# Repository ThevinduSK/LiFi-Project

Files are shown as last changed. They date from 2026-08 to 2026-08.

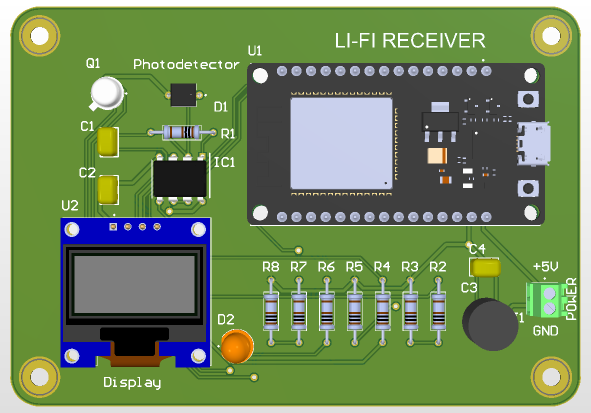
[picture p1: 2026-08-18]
PCB/Receiver/PCB 3D Print/PCB1.png

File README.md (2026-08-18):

# ESP32 Li-Fi Communication and Security Demonstrator

This repository contains the firmware and design files for a three-node
visible-light communication experiment:

1. A **transmitter** sends short messages by switching a high-power white LED.
2. A **legitimate receiver** detects the light with a BPW34 photodiode and
   displays valid messages on an OLED.
3. An **eavesdropper receiver** will later be used to measure how much of the
   optical signal can be recovered from an unintended position.

The current firmware is a compiled proof-of-concept for the first two nodes.
It uses on-off keying (OOK), Manchester line coding, framed messages, CRC-8
error detection, and a 38 kHz infrared acknowledgment path. It has not yet
been validated on the assembled PCBs.

For the complete design, security scope, implementation status, and test plan,
see [Project Technical Design and Status](docs/PROJECT_TECHNICAL_DESIGN_AND_STATUS.md).

## Current status

| Area | Status |
|---|---|
| PlatformIO ESP32 project | Implemented |
| Transmitter and receiver pin definitions | Implemented from supplied schematics |
| OOK and Manchester transmitter | Implemented and compiles |
| ADC Manchester receiver | Implemented and compiles |
| Message framing and CRC-8 | Implemented and compiles |
| OLED message display | Implemented and compiles |
| 38 kHz IR acknowledgment | Implemented and compiles |
| Separate hardware diagnostic firmware | Planned next |
| On-demand `A` link-quality handshake | Planned next |
| Simple `B` normal-message mode | Planned next |
| SNR and known-sequence success measurement | Planned next |
| Physical PCB testing and tuning | Not started |
| Eavesdropper experiment | Deferred until the legitimate link is stable |
| Encryption/authentication | Not implemented; optional later scope |

“Compiles” means PlatformIO successfully built the firmware. It does not mean
that the code has been uploaded to a board or that the optical thresholds and
timing have been proven on the physical link.

## Intended user workflow

The next firmware revision will use a deliberately small interface:

- Press `A` to run a link test. The transmitter sends a known optical sequence.
  The receiver estimates optical SNR and bit success rate, displays the result,
  and returns an IR result to the transmitter.
- Press `B` to enter normal message mode. Enter a short message, use `*` to
  erase, and press `#` to transmit.
- Normal messages will retain a short start marker and CRC, but will not repeat
  the full training/calibration sequence or wait for an IR ACK after every
  message.
- Run `A` again when the distance, alignment, ambient lighting, or LED level
  changes significantly.

The code currently in `src/transmitter` and `src/receiver` is the earlier full
prototype: it performs optical calibration and waits for an IR ACK on every
message. That behavior is documented, but will be simplified in the next
implementation stage.

## Hardware pin map

The pin assignments below match the supplied transmitter and receiver
schematics.

### Transmitter ESP32

| Function | GPIO |
|---|---:|
| White LED MOSFET gate | 18 |
| Warning/status LED | 23 |
| IR acknowledgment receiver | 19 |
| Keypad rows R1-R4 | 13, 14, 27, 26 |
| Keypad columns C1-C4 | 25, 33, 32, 16 |

### Legitimate receiver ESP32

| Function | GPIO |
|---|---:|
| BPW34/LM358 analog output | 34 |
| IR acknowledgment transmitter | 18 |
| OLED SDA | 21 |
| OLED SCL | 22 |

The transmitter firmware starts the high-power LED output in the OFF state.
LED current is determined by the external LED, supply, resistor, MOSFET, and
thermal design—not by the ESP32 firmware.

## Repository layout

```text
.
├── docs/                         Detailed design and progress document
├── include/
│   ├── lifi_protocol.hpp         Protocol constants and CRC-8
│   └── pin_config.hpp            Schematic-derived ESP32 pin assignments
├── PCB/
│   ├── Transmitter/              Transmitter schematic and fabrication files
│   └── Receiver/                 Receiver schematic and fabrication files
├── src/
│   ├── transmitter/main.cpp      Current transmitter proof-of-concept
│   ├── receiver/main.cpp         Current receiver proof-of-concept
│   └── eavesdropper/main.cpp     Placeholder for the later experiment
└── platformio.ini                PlatformIO environments and dependencies
```

## Building with PlatformIO

Open this repository as the project folder in VS Code. PlatformIO should show
the `transmitter`, `receiver`, and `eavesdropper` environments.

Build the two active nodes:

```bash
pio run -e transmitter
pio run -e receiver
```

Upload one environment after connecting the correct ESP32:

```bash
pio run -e transmitter -t upload
pio run -e receiver -t upload
```

Open the serial monitor at 115200 baud:

```bash
pio device monitor --baud 115200
```

Do not connect both ESP32 boards at once unless the upload port is selected
explicitly. Before powering the high-power LED stage, verify its supply,
polarity, current-limiting component, and thermal requirements.

## Current proof-of-concept controls

These controls describe the code presently in the repository, before the
planned `A`/`B` mode separation:

- `0-9` and `A-D`: append a character.
- `*`: erase the last character.
- `#`: transmit the message.
- Serial Monitor input follows the same rules; newline also transmits.
- Maximum message length: 16 characters.

## Important security statement

This is a **Li-Fi security demonstrator**, not yet a secure messaging product.
Directional visible light may reduce casual signal exposure, but it does not
guarantee confidentiality. CRC detects accidental corruption; it does not
authenticate a sender or prevent deliberate modification. The IR ACK proves
only that an IR response was detected, not that no passive eavesdropper was
present.

The security contribution will be the measured comparison between the
legitimate receiver and an eavesdropper under controlled placement, angle,
distance, obstruction, and ambient-light conditions. Cryptographic protection
can be added later if it becomes part of the project scope.

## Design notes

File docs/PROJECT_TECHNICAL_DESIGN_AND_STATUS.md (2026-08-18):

# Li-Fi Communication and Security Demonstrator

## Technical Design and Project Status

**Document date:** 18 August 2026  
**Implementation platform:** ESP32 DevKit V1, Arduino framework, PlatformIO  
**Project stage:** Legitimate transmitter/receiver proof-of-concept; hardware
bring-up and simplified operating modes are the next milestone

## 1. Executive summary

The project demonstrates short-range digital communication through visible
light and studies the practical security boundary of that link. A transmitter
modulates a high-power white LED, a legitimate receiver recovers the data with
a photodiode circuit, and a later eavesdropper node attempts to recover the same
data from unintended locations.

The first software proof-of-concept is present and builds successfully. It can:

- accept a short message from a 4x4 keypad or Serial Monitor;
- encode it into a structured frame;
- transmit the frame through the white LED using on-off keying and Manchester
  line coding;
- sample the photodiode amplifier through the receiver ESP32 ADC;
- validate a received frame with CRC-8;
- display a valid payload on the OLED; and
- return a 38 kHz IR acknowledgment to the transmitter.

This code has not yet been proven on the assembled PCBs. It also performs a
calibration preamble and acknowledgment for every message, which is more
complex than needed for the first demonstration. The agreed next revision will
separate an on-demand link test from normal message transmission:

- `A`: run a known-sequence link test, measure quality, show the result, and
  return an IR response;
- `B`: enter normal message mode and send short messages using the most recent
  link calibration.

The eavesdropper work will begin only after this basic legitimate link is
repeatable.

## 2. Project purpose and scope

### 2.1 Primary objectives

1. Establish a repeatable one-way visible-light data link between two ESP32
   systems.
2. Provide a simple keypad-operated demonstration that is easy to understand.
3. Measure legitimate link quality using a known test sequence.
4. Build a third receiving node and compare its recovery performance against
   the legitimate receiver.
5. Record how geometry and environment affect both communication reliability
   and exposure to eavesdropping.

### 2.2 Initial deliverable

The initial deliverable is a laboratory demonstrator, not a high-speed Li-Fi
network. It prioritizes observable operation, simple debugging, and repeatable
measurements over data rate.

### 2.3 Items outside the current implementation

- encryption and cryptographic authentication;
- high-speed data transfer;
- automatic detection of every passive optical eavesdropper;
- production-grade error correction;
- automatic gain control in the analog receiver;
- completed eavesdropper firmware and hardware validation.

These can be evaluated after the base optical link is stable.

## 3. System architecture

```mermaid
flowchart LR
    K[4x4 keypad] --> TX[Transmitter ESP32]
    TX --> M[LED MOSFET driver]
    M --> W[High-power white LED]
    W -->|Visible-light OOK + Manchester| P[BPW34 + LM358 receiver]
    P --> RX[Legitimate receiver ESP32]
    RX --> O[OLED result/message]
    RX --> IRT[38 kHz IR LED]
    IRT -->|Link-test result / ACK| IRR[IR receiver]
    IRR --> TX
    W -.->|Later measurement path| E[Eavesdropper receiver]
```

The main data path is visible light from transmitter to receiver. The return
path is infrared and is intended only for a short status response. The
transmitter does not contain a visible-light photodiode, so the optical data
path itself is one-way.

## 4. Hardware interfaces and exact ESP32 pins

The following assignments were taken from the supplied `Job1.PDF` transmitter
and `Job2.PDF` receiver schematics and are centralized in
`include/pin_config.hpp`.

### 4.1 Transmitter

| Circuit function | ESP32 signal | GPIO | Firmware direction |
|---|---|---:|---|
| White LED MOSFET gate | `LED_GATE` | 18 | Output |
| Red warning/status LED | `WARNING_LED` | 23 | Output |
| IR receiver signal | `IR_ACK` | 19 | Input |
| Keypad row 1 | `KEY_R1` | 13 | Matrix I/O |
| Keypad row 2 | `KEY_R2` | 14 | Matrix I/O |
| Keypad row 3 | `KEY_R3` | 27 | Matrix I/O |
| Keypad row 4 | `KEY_R4` | 26 | Matrix I/O |
| Keypad column 1 | `KEY_C1` | 25 | Matrix I/O |
| Keypad column 2 | `KEY_C2` | 33 | Matrix I/O |
| Keypad column 3 | `KEY_C3` | 32 | Matrix I/O |
| Keypad column 4 | `KEY_C4` | 16 | Matrix I/O |

The ESP32 controls the LED indirectly through the MOSFET gate. The software
sets GPIO18 LOW during startup so the optical LED remains off until an explicit
transmission or test.

### 4.2 Legitimate receiver

| Circuit function | ESP32 signal | GPIO | Firmware direction |
|---|---|---:|---|
| BPW34/LM358 analog signal | `LIFI_ADC` | 34 | ADC input |
| IR LED driver | `IR_TX` | 18 | PWM output |
| OLED data | `OLED_SDA` | 21 | I2C |
| OLED clock | `OLED_SCL` | 22 | I2C |

GPIO34 is input-only on the ESP32 and is suitable for the ADC signal. The
firmware currently configures a 12-bit ADC reading and 11 dB attenuation. The
actual usable range, noise, polarity, and saturation point must be measured on
the physical PCB.

### 4.3 Hardware boundary

Firmware determines when the MOSFET is switched, but it does not set or safely
limit the high-power LED current. LED current and heat are governed by the
external supply, LED forward voltage, series/current-control component,
MOSFET, PCB traces, and thermal design. Those values must be verified before a
continuous LED test. Short test pulses should be used during initial bring-up.

## 5. Software organization

The project uses PlatformIO so each ESP32 role can be built independently from
one repository.

| Environment | Source | Purpose | Present status |
|---|---|---|---|
| `transmitter` | `src/transmitter/main.cpp` | Keypad input and optical transmission | Builds |
| `receiver` | `src/receiver/main.cpp` | ADC decoding, OLED, and IR ACK | Builds |
| `eavesdropper` | `src/eavesdropper/main.cpp` | Later passive receiver experiment | Placeholder |

Shared protocol timing, frame limits, and CRC are in
`include/lifi_protocol.hpp`. Shared pin assignments are in
`include/pin_config.hpp`.

The next revision should add two separate diagnostic environments before the
main application is changed:

| Proposed environment | Purpose |
|---|---|
| `tx_diagnostic` | Verify keypad, warning LED, optical LED pulses, and IR input separately |
| `rx_diagnostic` | Verify ADC levels/noise, OLED, and a manually requested IR burst separately |

This lets each PCB function be proven without depending on the complete
communications protocol.

## 6. Modulation and line coding

### 6.1 Optical modulation: on-off keying

The project uses **intensity modulation with direct detection**. At the
firmware level this is on-off keying (OOK):

- MOSFET enabled: optical LED is ON;
- MOSFET disabled: optical LED is OFF;
- the photodiode/amplifier converts received optical intensity into an ADC
  level.

Only intensity is varied; the light does not use radio-frequency phase or
frequency modulation.

### 6.2 Line coding: Manchester

The raw OOK states are arranged as Manchester-coded bits. Every data bit has
two equal halves with a transition in the middle:

| Logical bit | First half | Second half |
|---:|---|---|
| `1` | Light ON | Light OFF |
| `0` | Light OFF | Light ON |

With the current constants, one optical half-symbol lasts 10 ms, giving 100
optical half-symbols per second. One complete Manchester data bit lasts 20 ms,
so the logical data-bit rate is:

```text
1 / 0.020 seconds = 50 bits per second
```

The useful payload rate is lower because every packet also carries
synchronization, header, and CRC data. At the current timing, a one-character
frame takes about 0.92 seconds and a maximum 16-character frame takes about
3.32 seconds, before the ACK wait. This slow initial setting is deliberate: it
gives the ESP32 ADC and analog front-end a generous sampling window during
bring-up. It can be increased only after oscilloscope/ADC measurements show
adequate settling and noise margin.

Manchester coding was chosen because:

- every bit contains a transition, making timing easier to observe;
- long runs of constant light or darkness cannot occur inside encoded data;
- each bit contains both an ON and OFF interval, reducing dependence on the
  absolute DC light level;
- invalid same-level pairs can be rejected immediately.

The cost is twice as many optical intervals as simple non-return-to-zero OOK.

### 6.3 Current frame format

The current proof-of-concept sends the following sequence for every message:

```text
60 ms dark idle
60 ms light sync
40 ms dark calibration
Manchester data bytes
20 ms dark guard
```

The Manchester data bytes are:

| Order | Field | Size | Purpose |
|---:|---|---:|---|
| 1 | Magic | 1 byte | Fixed `0xD3` frame identifier |
| 2 | Sequence | 1 byte | Distinguishes a new frame from a duplicate |
| 3 | Length | 1 byte | Payload length from 1 to 16 bytes |
| 4 | Payload | 1-16 bytes | Keypad/Serial message |
| 5 | CRC-8 | 1 byte | Detects accidental frame errors |

Bits are sent most-significant bit first. CRC-8 uses polynomial `0x07`, an
initial value of zero, and covers the magic, sequence, length, and payload.

### 6.4 Current receiver decision process

The receiver continuously learns an idle ADC level. A sufficiently large
change starts preamble detection. It then samples the known bright and dark
parts of the preamble and classifies later samples by whichever reference they
are closest to.

For each Manchester bit the receiver samples both halves:

- light then dark is decoded as `1`;
- dark then light is decoded as `0`;
- two equal classifications are rejected as an invalid Manchester symbol.

The receiver accepts a message only if the magic, length, Manchester symbols,
and CRC are valid.

### 6.5 IR return path

The receiver currently generates three short bursts of approximately 38 kHz
IR after a valid frame. A demodulating IR receiver on the transmitter reports
the burst as an active-low input. The transmitter waits up to 700 ms and lights
its warning LED if no response is seen.

This is a reliability acknowledgment. It is not proof of receiver identity and
not proof that an eavesdropper was absent.

## 7. Simplified target operating modes

The first code is intentionally being simplified before hardware trials. The
target design separates expensive training from normal user messages.

### 7.1 Idle state

At startup:

- optical LED is OFF;
- warning/status LED is OFF;
- transmitter waits for a mode key;
- receiver monitors its ADC and waits for either a link-test or message marker.

### 7.2 `A` — on-demand link test and calibration

Pressing `A` will start a deliberate handshake:

1. The transmitter sends a long, known ON/OFF training pattern.
2. The receiver measures the bright level, dark level, and noise.
3. The transmitter sends a known bit sequence, for example repeated `0x55` and
   `0xAA` bytes.
4. The receiver compares every decoded bit with the expected bit.
5. The receiver calculates an optical SNR estimate and bit success rate.
6. The OLED shows the result and a simple `OK`, `MARGINAL`, or `FAIL` state.
7. The receiver sends a short IR result/ACK.
8. Only while waiting for this result does the transmitter treat its IR input
   as part of the application workflow.
9. If the test passes, the measured bright/dark threshold is cached for later
   normal messages.

This handshake is user-controlled. It should be repeated after changing
distance, alignment, room lighting, receiver gain, or LED power.

### 7.3 `B` — normal message mode

Pressing `B` will enter message entry:

- keypad characters are appended to a short buffer;
- `*` removes the last character;
- `#` sends the message;
- `B` can cancel/exit message entry if desired in the final UI;
- the receiver displays a message only after a valid CRC.

A normal message still requires a **short start marker** so that an idle
receiver knows where the first bit begins. It will retain length and CRC
framing, but it will not repeat the full bright/dark training sequence and will
not require an IR ACK for every message. It will use the calibration cached by
the most recent successful `A` link test.

This is the simplest practical separation: full measurement when requested,
minimal framing during normal communication.

## 8. Link-quality measurements

### 8.1 Optical SNR estimate

During the known training intervals, the receiver can collect multiple ADC
samples for ON and OFF states. Let:

- `mean_on` be the average ADC value during known light-ON intervals;
- `mean_off` be the average ADC value during known light-OFF intervals;
- `sigma_on` and `sigma_off` be their standard deviations.

A practical pooled noise estimate is:

```text
noise = sqrt((sigma_on^2 + sigma_off^2) / 2)
signal_separation = abs(mean_on - mean_off)
SNR_dB = 20 * log10(signal_separation / noise)
```

This is an ADC-domain optical quality estimate for this demonstrator. It should
not be represented as a calibrated RF-style SNR measurement unless the analog
front-end and measurement method are independently calibrated.

ADC clipping also needs to be checked. A large apparent separation is not
useful if the amplifier is saturating at either rail.

### 8.2 Known-sequence success rate and BER

If `N` known test bits are sent and `errors` bits differ from the expected
sequence:

```text
BER = errors / N
success_percent = 100 * (N - errors) / N
```

Both should be displayed or logged. A frame-level pass alone is not enough for
experimentation because it hides how close the link is to failure.

### 8.3 Initial provisional categories

The following values are starting points for laboratory tuning, not final
specifications:

| State | Proposed initial rule |
|---|---|
| `OK` | SNR at least 10 dB and success at least 95% |
| `MARGINAL` | SNR at least 6 dB and success at least 80% |
| `FAIL` | Below either marginal threshold or no valid response |

Final thresholds should be selected from collected test data, especially data
near the distance and angle where messages begin to fail.

## 9. Security work and claims

### 9.1 Threat model for the demonstrator

The main research question is whether a passive receiver outside the intended
optical path can recover transmitted data. Relevant variables include:

- transmitter-to-receiver distance;
- direct alignment and viewing angle;
- LED beam spread and reflections from walls/surfaces;
- obstruction of the direct path;
- ambient sunlight or artificial light;
- receiver gain, field of view, and physical shielding;
- eavesdropper location relative to the legitimate receiver.

Later experiments may also discuss active optical injection, replay, or a
forged IR response, but these are separate threats from passive listening.

### 9.2 What the current design provides

| Mechanism | Actual benefit | Security limitation |
|---|---|---|
| Directional visible-light path | Can limit where a strong signal is available | Reflections and wider beam paths can leak data |
| Manchester validity checks | Reject malformed optical symbols | Not authentication |
| CRC-8 | Detects many accidental bit errors | An attacker can recompute it; not cryptographic integrity |
| Sequence byte | Suppresses an immediate duplicate in the current receiver | Wraps after 256 and does not prevent deliberate replay |
| IR acknowledgment | Confirms that some expected IR activity was observed | Can be blocked, copied, or forged; does not identify a receiver |
| Warning LED | Shows link/ACK failure in the current prototype | Does not detect a silent passive eavesdropper |

### 9.3 What must not be claimed

The project should not claim that visible light alone guarantees secrecy. An
eavesdropper may capture direct spill light or reflected light. The current
payload is plaintext. Anyone who can observe and decode the modulation can read
it.

The current design also cannot automatically detect a purely passive
eavesdropper. A passive device does not need to transmit anything, so its
presence creates no guaranteed signal at the legitimate nodes.

### 9.4 Planned security experiment

After the legitimate link is stable, the third ESP32 receiver should implement
the same raw optical sampling and decoder without participating in the IR
handshake. Tests should transmit the same known sequence to both receivers and
record:

- legitimate receiver ADC ON/OFF means, noise, SNR estimate, BER, and valid
  frame count;
- eavesdropper ADC ON/OFF means, noise, SNR estimate, BER, and valid frame
  count;
- distance, angle, offset, obstruction, room-light condition, and receiver
  configuration.

The useful result is a measured spatial boundary:

- region where the legitimate receiver is reliable;
- region where an eavesdropper can also decode reliably;
- region where energy is observable but data cannot be recovered;
- region where neither receiver can decode.

This provides an evidence-based security assessment instead of assuming that
line-of-sight automatically means confidentiality.

### 9.5 Optional later cryptographic layer

If confidential data must be transmitted, physical directionality
should be supplemented with authenticated encryption and managed keys. A
challenge-response handshake can also authenticate the legitimate receiver.
These mechanisms are deliberately not presented as implemented in the current
project and should be separately specified before development.

## 10. Verification strategy

### Phase 1 — software-only checks

- build every PlatformIO environment;
- verify frame construction and CRC with known test vectors;
- verify mode-state behavior through Serial Monitor;
- confirm LED outputs default to OFF.

### Phase 2 — transmitter diagnostic firmware

- identify every keypad key and verify the row/column mapping;
- pulse the status LED;
- pulse the optical LED briefly at a safe hardware current;
- display raw IR input changes in Serial Monitor;
- verify that no output remains unintentionally active after reset.

### Phase 3 — receiver diagnostic firmware

- confirm OLED address, startup, and text output;
- stream ADC mean, minimum, maximum, and noise with the LED OFF;
- repeat with known LED ON/OFF states;
- check amplifier polarity and ADC saturation;
- manually transmit a 38 kHz IR burst and verify it at the transmitter.

### Phase 4 — `A` link test

- send the known optical training sequence;
- calculate and display SNR, errors, and success rate;
- return IR pass/fail status;
- tune timing and provisional thresholds from measured data.

### Phase 5 — `B` normal messages

- enter, edit, cancel, and send keypad messages;
- confirm a short start marker is detected reliably using cached calibration;
- reject bad Manchester symbols, invalid length, and bad CRC;
- verify behavior after lighting/alignment changes and a new `A` test.

### Phase 6 — eavesdropper experiment

- implement passive capture without an ACK;
- run a defined position/angle/distance matrix;
- export consistent logs from both receivers;
- analyze legitimate reliability against unintended recoverability.

## 11. Acceptance criteria for the first demonstration

The first milestone can be considered complete when:

1. Both diagnostic firmwares verify every connected peripheral.
2. Pressing `A` produces a repeatable OLED link-quality result and an IR result
   at the transmitter.
3. Pressing `B`, entering a short message, and pressing `#` displays the same
   message at the legitimate receiver.
4. Invalid or corrupted frames are not displayed as valid messages.
5. Ten consecutive link tests at the agreed demonstration distance meet the
   selected success threshold under the selected lighting condition.
6. Timing, LED configuration, receiver gain, distance, and ambient conditions
   are recorded so the demonstration can be reproduced.

The eavesdropper investigation is a later milestone and should not block this
initial legitimate-link acceptance.

## 12. Current progress and next actions

### Completed in the repository

- PlatformIO project configured for ESP32 DevKit V1 and Arduino framework.
- Schematic-derived transmitter and receiver pin map added.
- Keypad/Serial message buffer implemented.
- OOK Manchester encoder implemented.
- Bright/dark preamble and ADC Manchester decoder implemented.
- Magic, sequence, length, payload, and CRC-8 framing implemented.
- OLED display and IR acknowledgment implemented.
- Transmitter and receiver environments compiled successfully.
- Eavesdropper environment reserved with a placeholder.

### Not yet completed

- firmware upload and physical PCB testing;
- separate transmitter and receiver diagnostic builds;
- `A` link-test state and quality calculation;
- `B` normal-message state with cached calibration;
- removal of full training and ACK from every normal message;
- measurement-driven timing/threshold tuning;
- eavesdropper implementation and controlled security trials.

### Recommended immediate sequence

1. Add and build `tx_diagnostic` and `rx_diagnostic` environments.
2. Test the two PCBs one peripheral at a time.
3. Record actual ADC ON/OFF/noise values and confirm optical polarity.
4. Implement and tune the `A` known-sequence link test.
5. Implement the `B` message mode using cached link calibration.
6. Run repeatability tests before starting eavesdropper development.

This order minimizes debugging uncertainty: each hardware interface is proven
first, then link measurement, then user messages, and finally the security
experiment.

## 13. Known risks and engineering notes

- Ambient light and the LM358 operating point may shift the ADC baseline.
- The analog signal may be inverted relative to expected light state; the
  closest-reference decoder can tolerate either polarity after calibration.
- Receiver saturation can look like a strong signal while destroying useful
  amplitude information.
- The present 50 bit/s setting is intentionally conservative and messages will
  take several seconds. Optimization should follow reliable operation.
- ESP32 software timing can contain jitter. If the data rate increases
  significantly, hardware timers, interrupts, or buffered sampling may be
  needed.
- A simple IR ACK can be affected by other IR sources and should remain a
  demonstration control path unless a stronger protocol is designed.
- PCB LED-current changes must be reviewed electrically; firmware cannot make
  an unsafe current-limiting design safe.
- Any project security statement should distinguish measured optical
  confinement from cryptographic confidentiality.

## 14. Project summary

The project currently has a complete software proof-of-concept for a slow,
framed, error-checked visible-light link between the transmitter and legitimate
receiver. The next milestone is not to add more protocol features; it is to
make the system easier to verify and operate by separating hardware diagnostics,
an on-demand link-quality handshake, and ordinary message transmission. Once
that link is measured and repeatable, the eavesdropper node will be used to
quantify—rather than assume—the physical security benefit of the optical path.

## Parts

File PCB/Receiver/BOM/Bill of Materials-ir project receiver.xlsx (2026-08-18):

Name | Description | Designator | Footprint | LibRef | Quantity
10pf |  | C1 | C320C | C320C104M5U5TA | 1
100nf |  | C2, C4 | C320C | C320C104M5U5TA | 2
10uf | Capacitor Polarised | C3 | CAPPRD350W65D800H1300 | 470uf | 1
BPW34 | Diode | D1 | BPW34 | BPW34 | 1
IR_LED | LED, 5MM, ORANGE; LED / Lamp Size: 5mm / T-1 3/4; LED Colour: Orange; Typ Luminous Intensity: 4.3mcd; Viewing Angle: ... | D2 | LEDRD254W57D500H1070 | L08R5000Q1 | 1
LM358P | Integrated Circuit | IC1 | DIP794W53P254L959H508Q8N | LM358P | 1
282834-2 | Terminal Block Connector PCB 2.54 mm 30-16 AWG Green 10 A 150 V M1.6 | TE Connectivity 282834-2 | J1 | TE_282834-2 | 282834-2 | 1
2N2222A | Transistor BJT NPN | Q1 | 2N2907A | 2N2222A | 1
220K | Resistor | R1 | resistor | 220ohm resistor throuh hole_1 | 1
10k | Resistor | R2, R4, R5, R8 | resistor | 220ohm resistor throuh hole_1 | 4
20k | Resistor | R3 | resistor | 220ohm resistor throuh hole_1 | 1
220 ohm | Resistor | R6 | resistor | 220ohm resistor throuh hole_1 | 1
1K | Resistor | R7 | resistor | 220ohm resistor throuh hole_1 | 1
ESP32-DEVKIT-V1 | Dual core, Wi-Fi: 2.4 GHz up to 150 Mbits/s,BLE (Bluetooth Low Energy) and legacy Bluetooth, 32 bits, Up to 240 MHz | U1 | MODULE_ESP32_DEVKIT_V1 | ESP32-DEVKIT-V1 | 1
DM-OLED096-636 | 0.96â€ 128 X 64 MONOCHROME GRAPHIC OLED DISPLAY MODULE - I2C | U2 | MODULE_DM-OLED096-636 | DM-OLED096-636 | 1

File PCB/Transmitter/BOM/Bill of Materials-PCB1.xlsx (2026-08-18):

Name | Description | Designator | Footprint | LibRef | Quantity
470uf | Capacitor Polarised | C1 | CAPPRD350W65D800H1300 | 470uf | 1
100nf |  | C2, C3 | C320C | C320C104M5U5TA | 2
White_LED | LED, 5MM, ORANGE; LED / Lamp Size: 5mm / T-1 3/4; LED Colour: Orange; Typ Luminous Intensity: 4.3mcd; Viewing Angle: ... | D1 | LEDRD254W57D500H1070 | L08R5000Q1 | 1
RED_LED | LED, 5MM, ORANGE; LED / Lamp Size: 5mm / T-1 3/4; LED Colour: Orange; Typ Luminous Intensity: 4.3mcd; Viewing Angle: ... | D2 | LEDRD254W57D500H1070 | L08R5000Q1 | 1
8 pin female header | Connector | J1 | SHDR8W99P0X254_1X8_2017X635X1124P | 8 pin female header | 1
801-93-003-10-001000 | Connector | J2 | RHDR3W60P0X254_1X3_762X254X701P | 801-93-003-10-001000 | 1
282834-2 | Terminal Block Connector PCB 2.54 mm 30-16 AWG Green 10 A 150 V M1.6 | TE Connectivity 282834-2 | J3 | TE_282834-2 | 282834-2 | 1
AO3400A | MOSFET (N-Channel) | Q1 | SOT95P280X125-3N | AO3400A | 1
3.3ohm | Resistor | R1 | resistor | 3.3ohm resistor throuh hole_1_1 | 1
330 ohm | Resistor | R2 | resistor | 3.3ohm resistor throuh hole_1_1 | 1
100ohm | Resistor | R3 | resistor | 100ohm resistor throuh hole_1_1 | 1
10k | Resistor | R4 | resistor | 10k resistor throuh hole_1 | 1
ESP32-DEVKIT-V1 | Dual core, Wi-Fi: 2.4 GHz up to 150 Mbits/s,BLE (Bluetooth Low Energy) and legacy Bluetooth, 32 bits, Up to 240 MHz | U1 | MODULE_ESP32_DEVKIT_V1 | ESP32-DEVKIT-V1 | 1

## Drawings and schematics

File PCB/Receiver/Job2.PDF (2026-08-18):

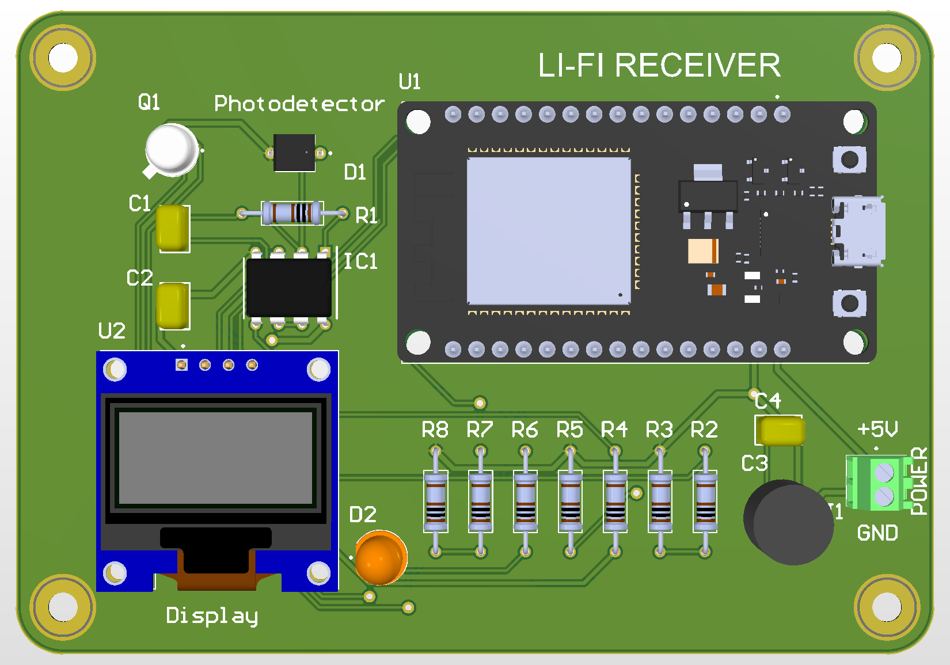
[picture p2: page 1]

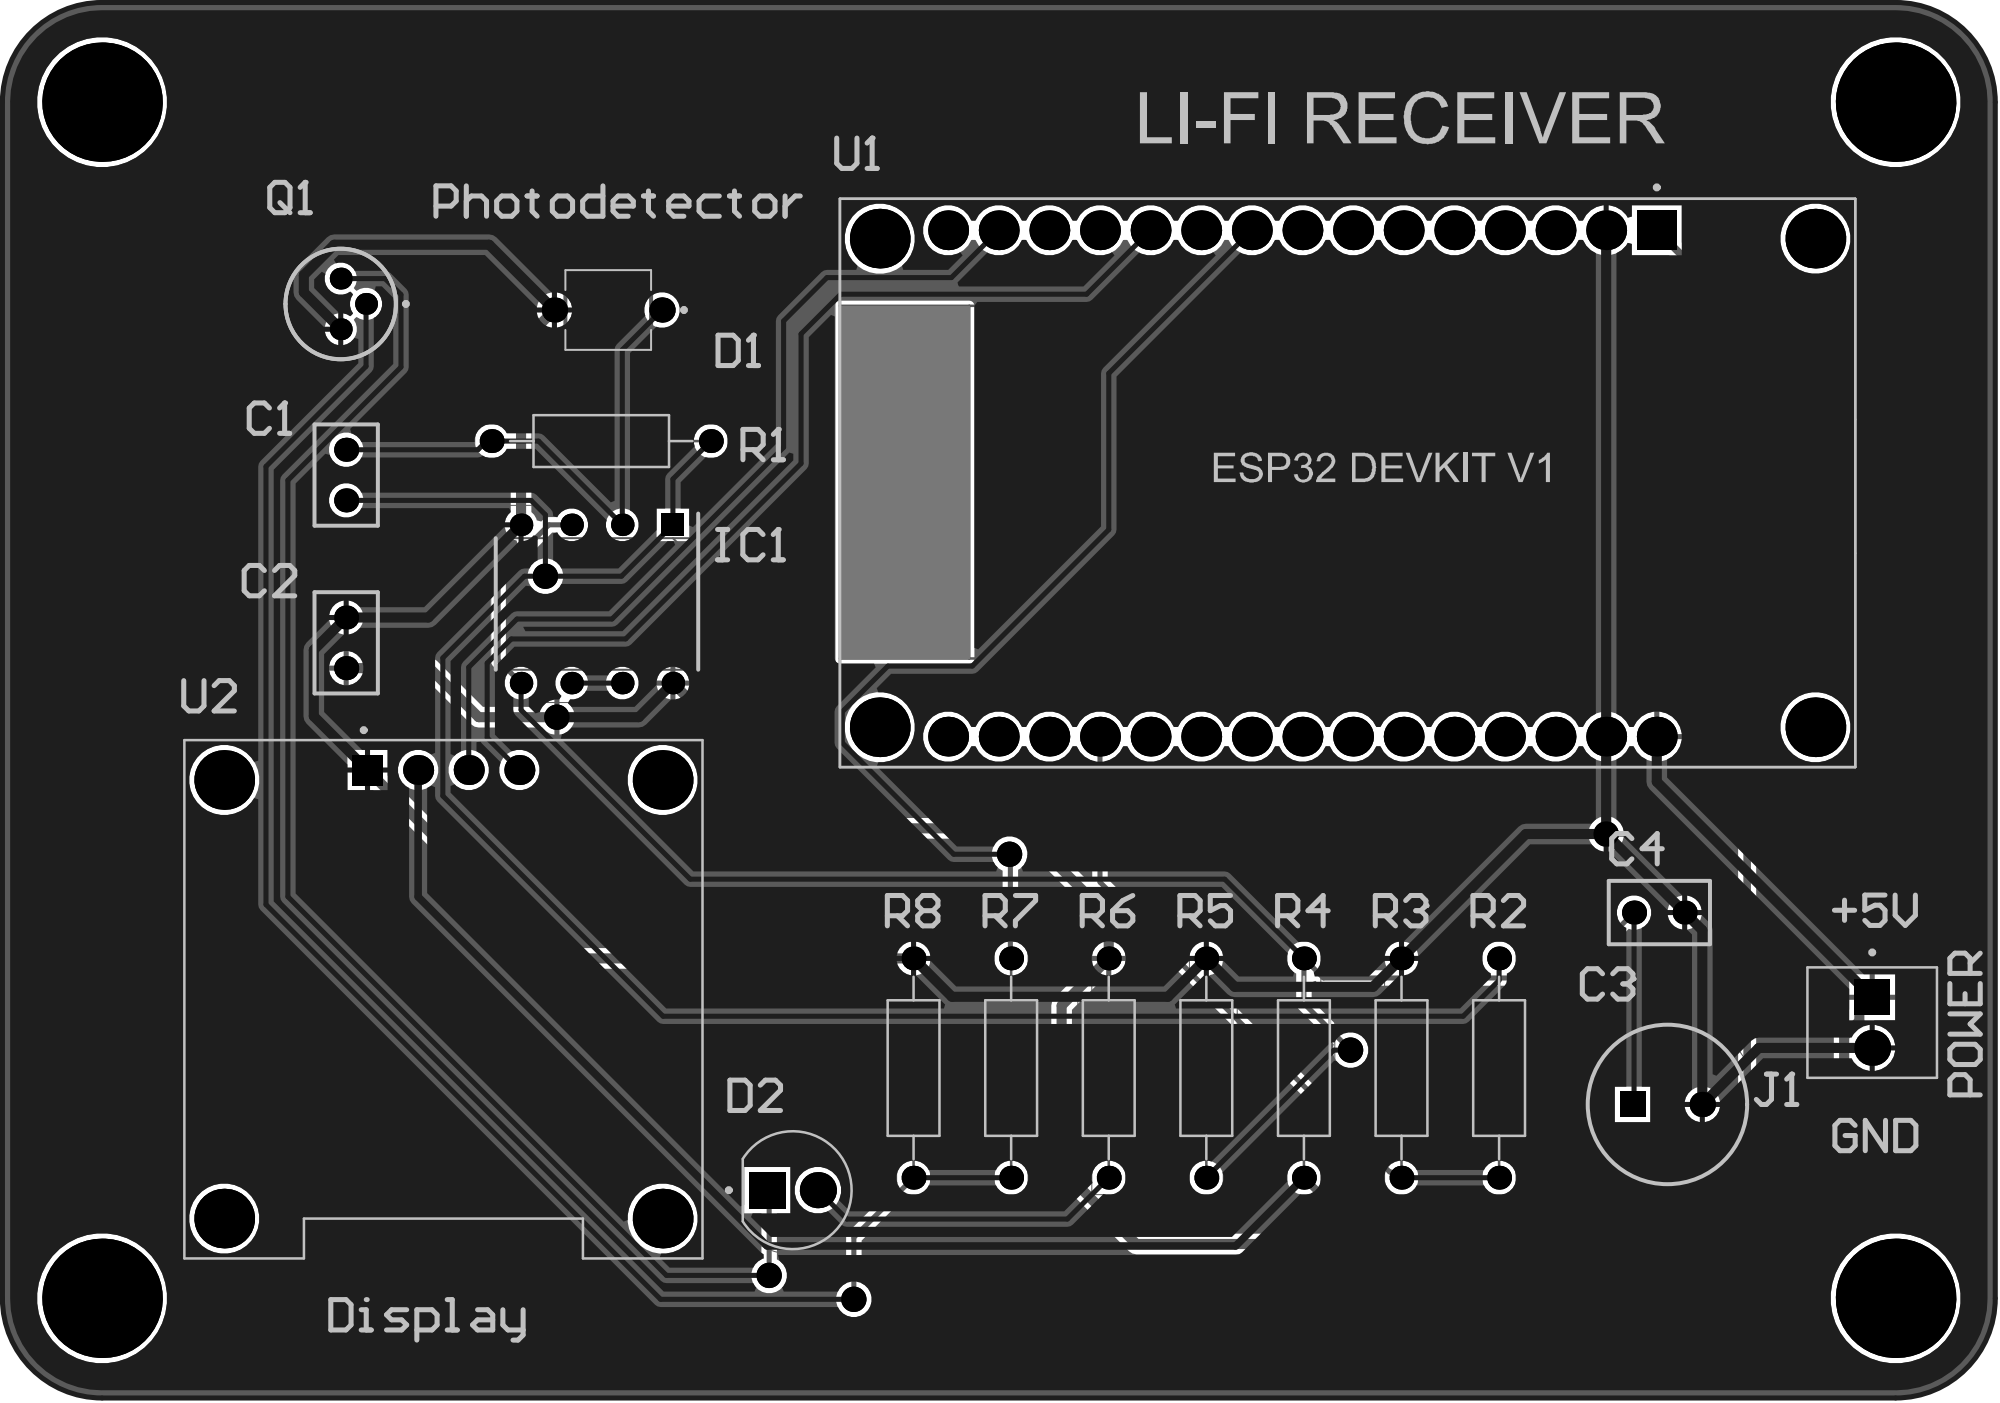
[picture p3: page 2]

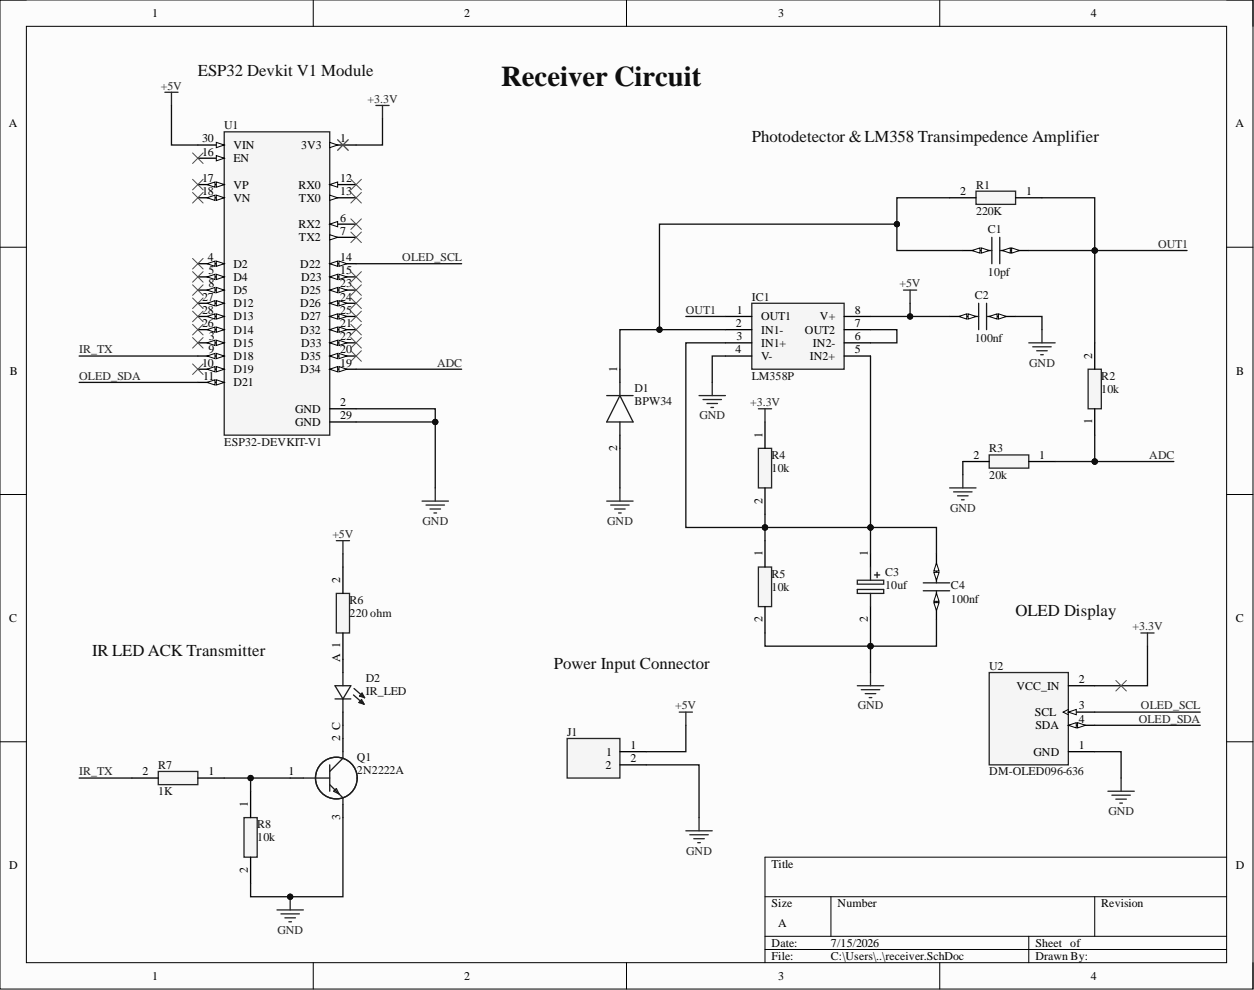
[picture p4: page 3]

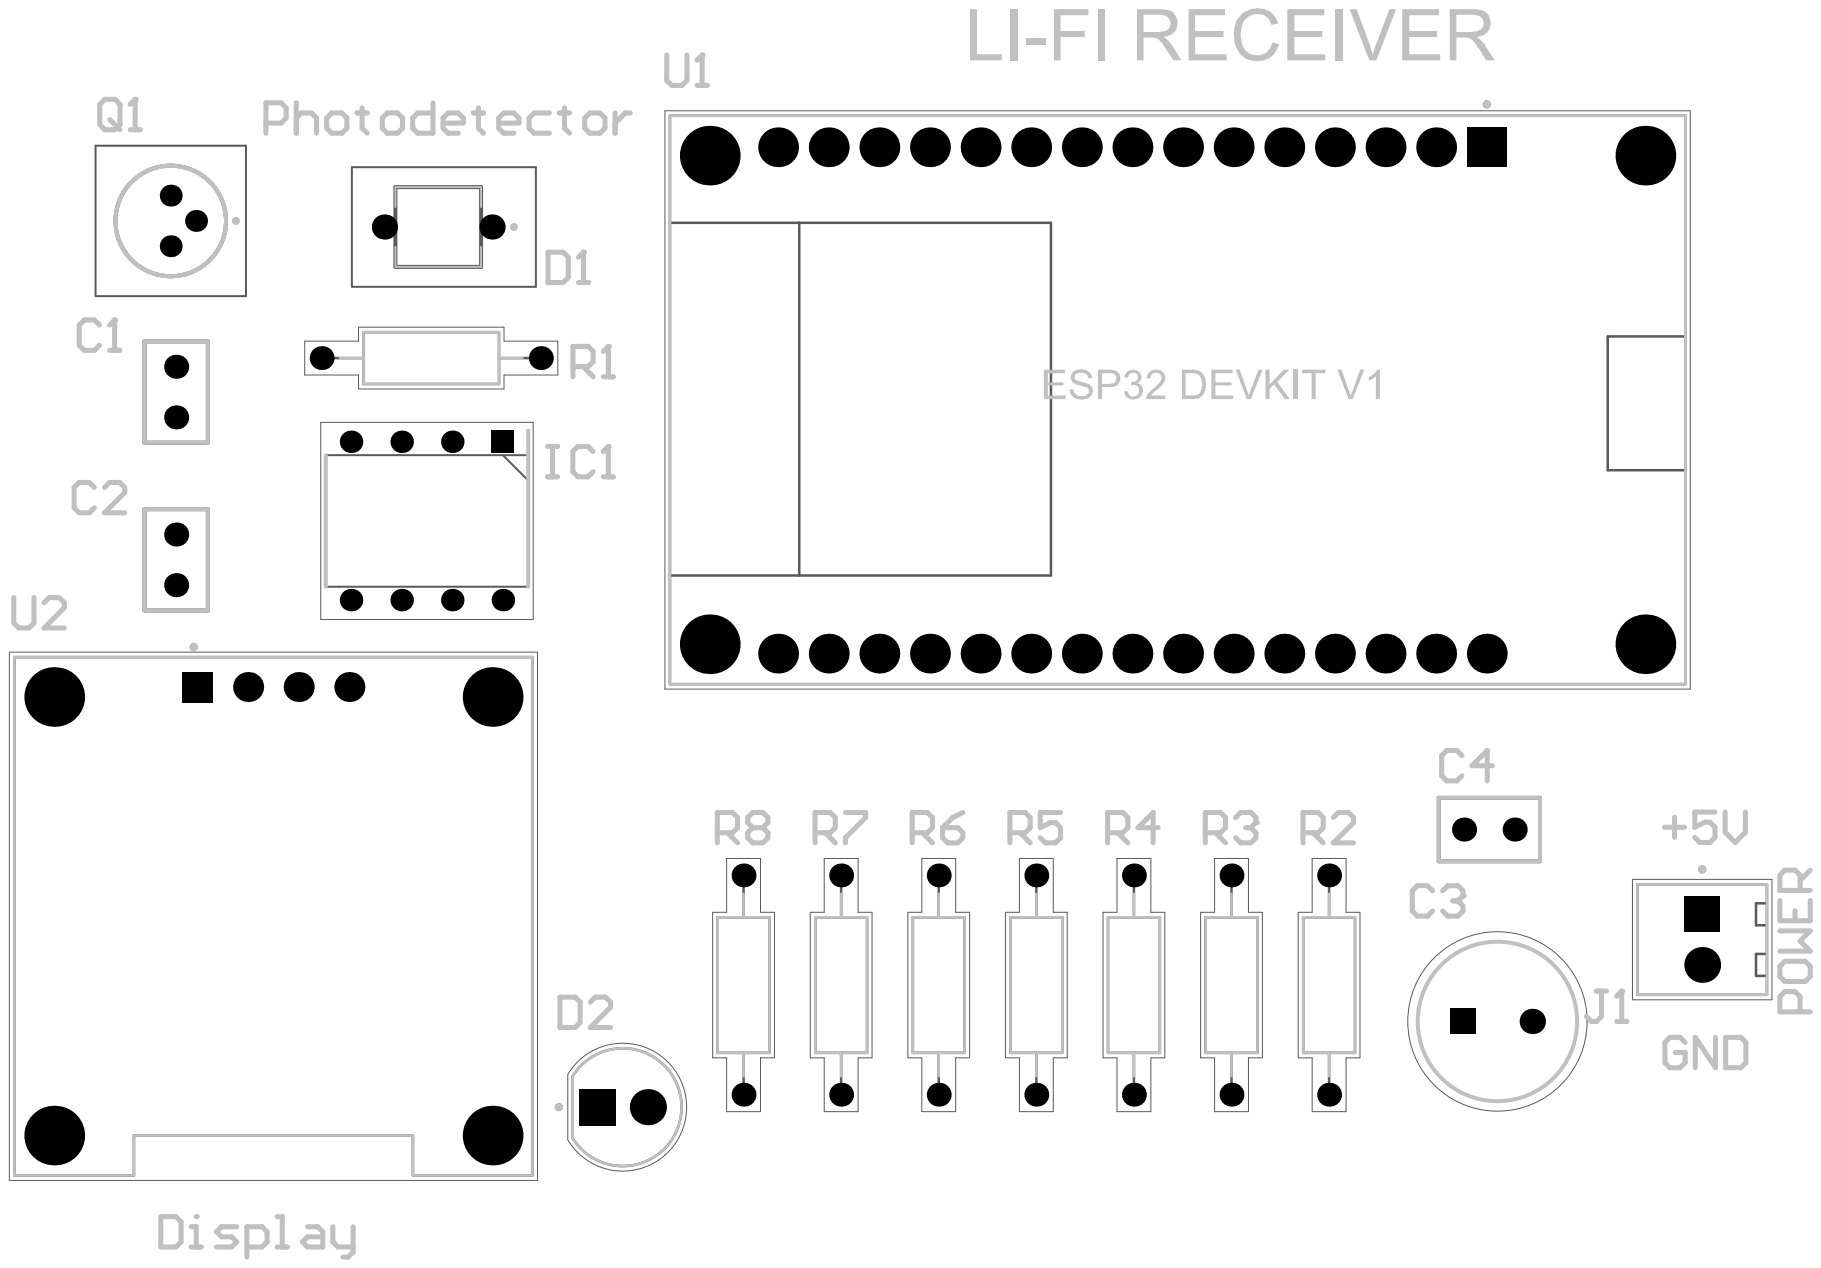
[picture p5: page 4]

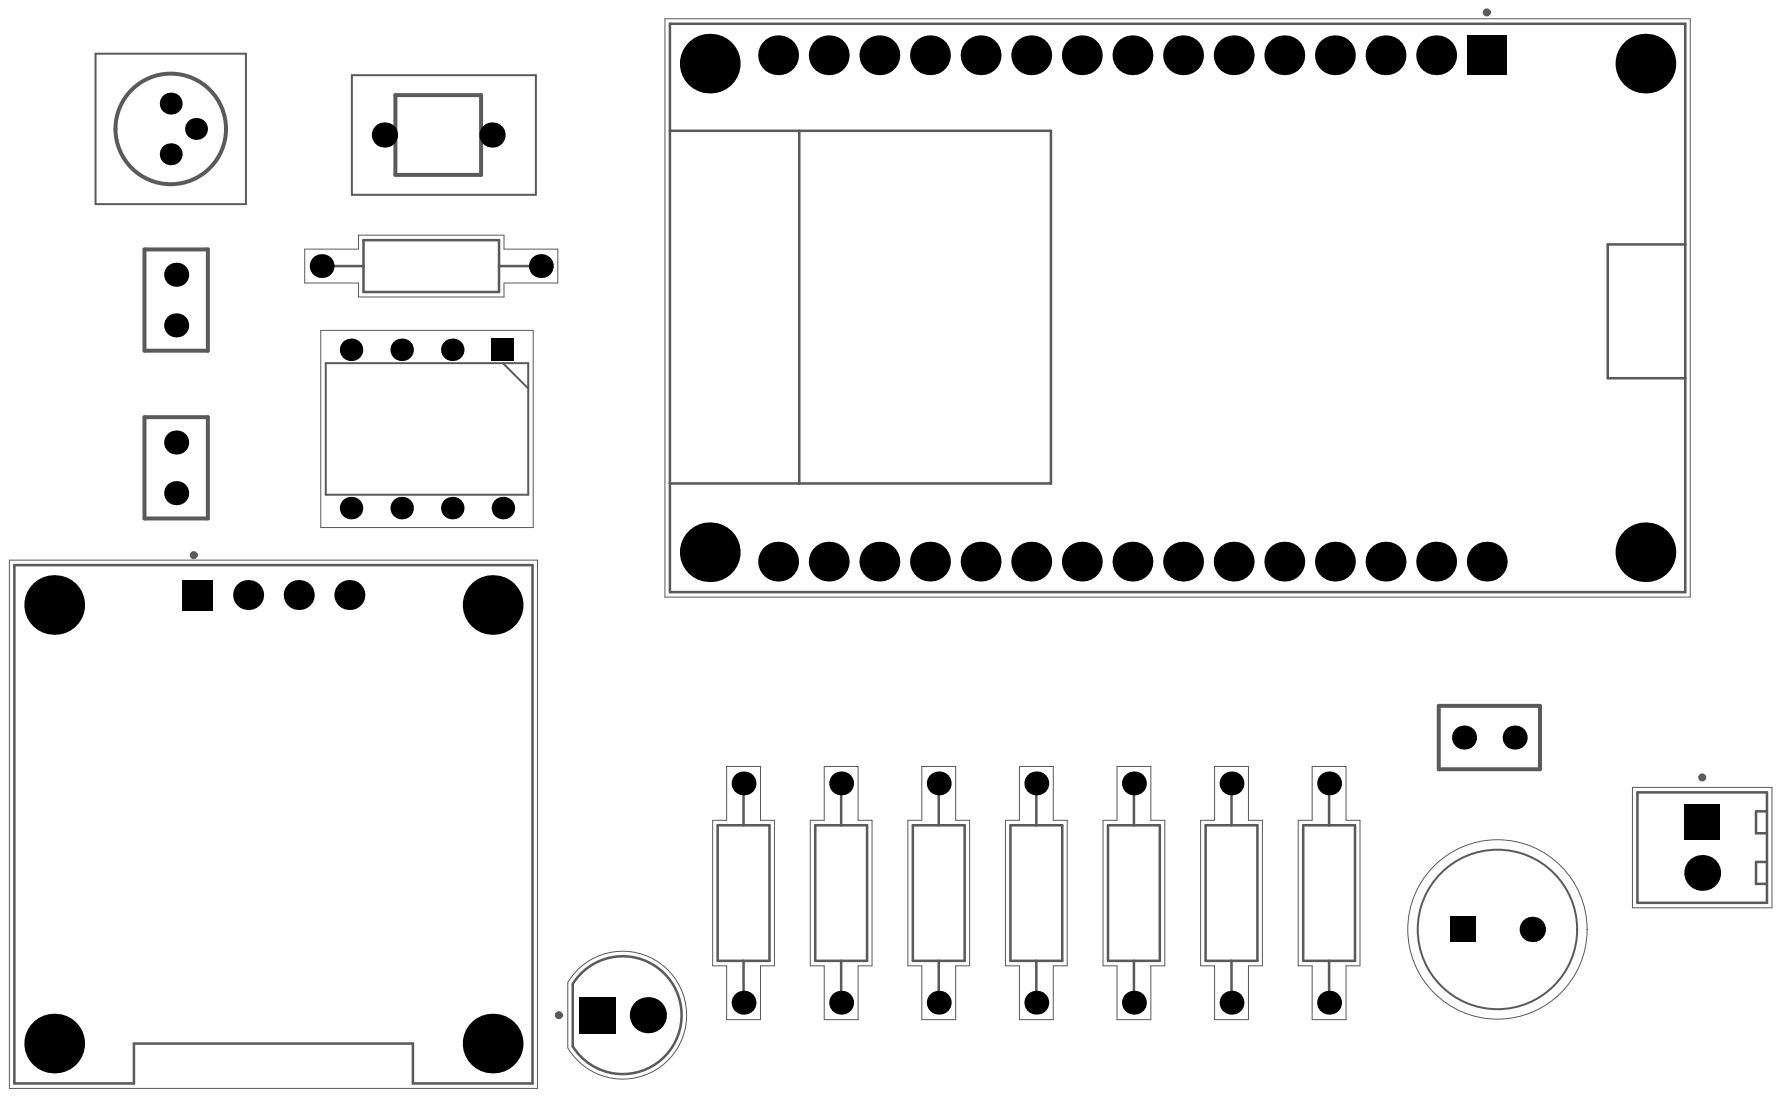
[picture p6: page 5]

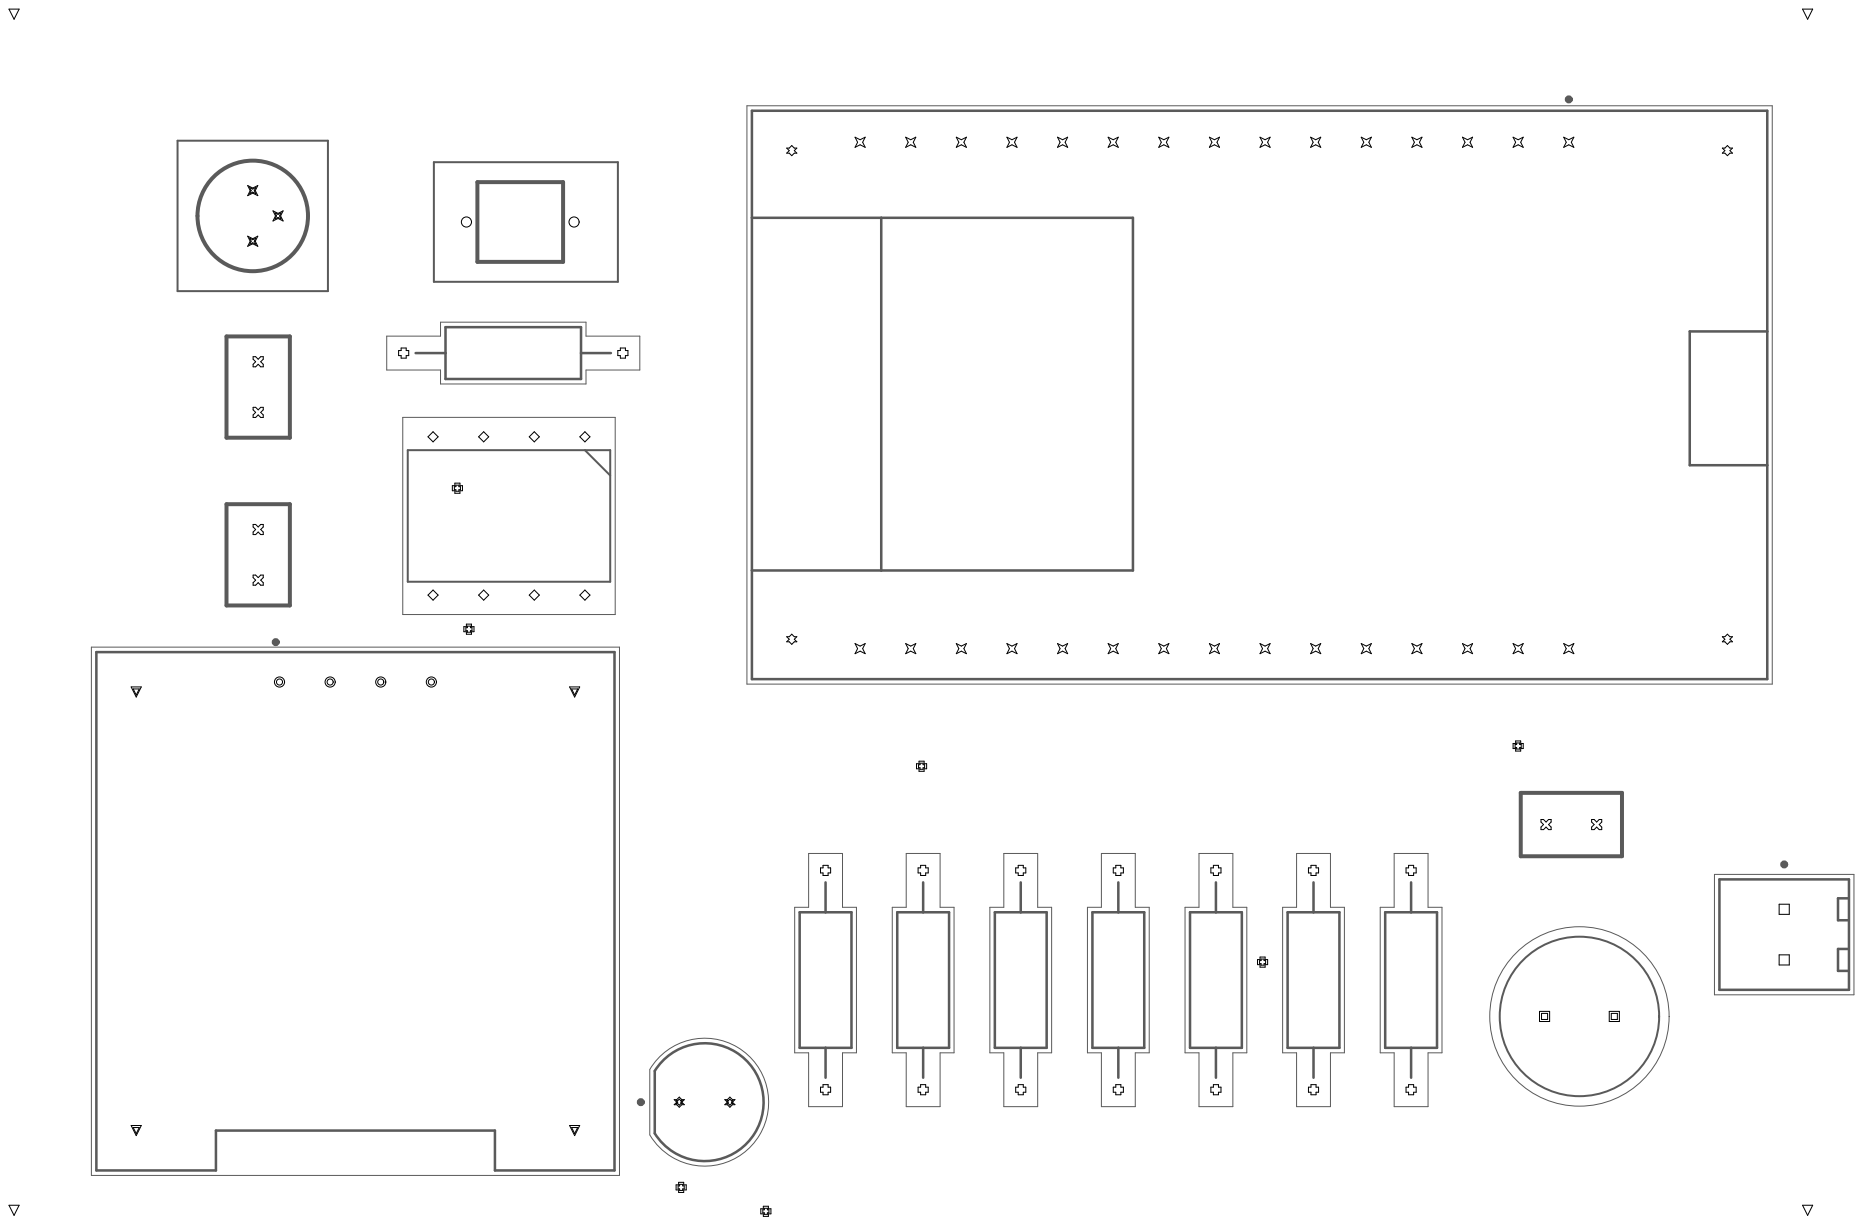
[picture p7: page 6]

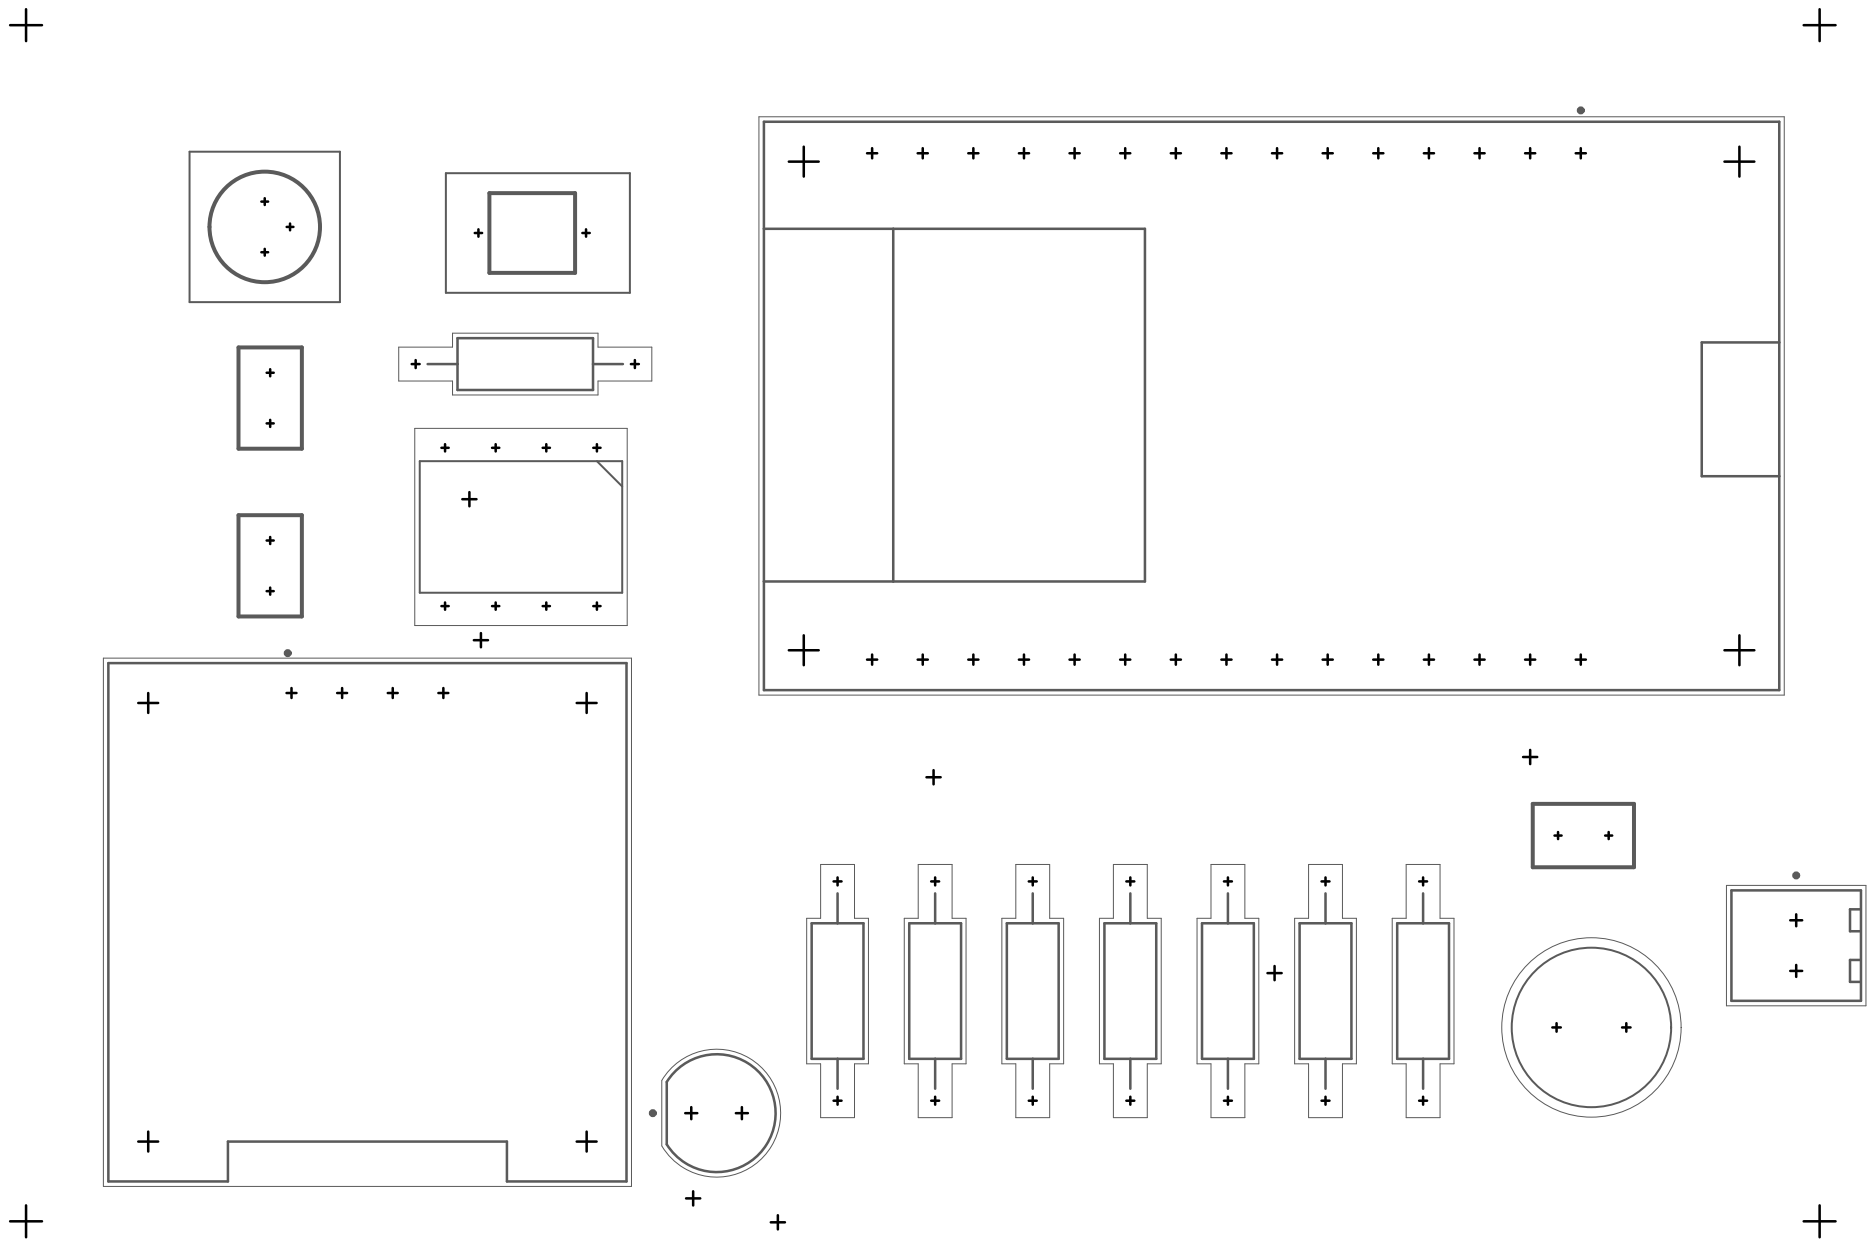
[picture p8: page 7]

Name | Description | Designator | Footprint | LibRef | Quantity
10pf | | C1 | C320C | C320C104M5U5TA | 1
100nf | | C2, C4 | C320C | C320C104M5U5TA | 2
10uf | Capacitor Polarised | C3 | CAPPRD350W65D800 H1300 | 470uf | 1
BPW34 | Diode | D1 | BPW34 | BPW34 | 1
IR_LED | LED, 5MM, ORANGE; LED / Lamp Size: 5mm / T-1 3/4; LED Colour: Orange; Typ Luminous Intensity: 4.3mcd; Viewing Angle: ... | D2 | LEDRD254W57D500H 1070 | L08R5000Q1 | 1
LM358P | Integrated Circuit | IC1 | DIP794W53P254L959 H508Q8N | LM358P | 1
282834-2 | Terminal Block Connector PCB 2.54 mm 30-16 AWG Green 10 A 150 V M1.6 | TE Connectivity 282834-2 | J1 | TE_282834-2 | 282834-2 | 1
2N2222A | Transistor BJT NPN | Q1 | 2N2907A | 2N2222A | 1
220K | Resistor | R1 | resistor | 220ohm resistor throuh hole_1 | 1
10k | Resistor | R2, R4, R5, R8 | resistor | 220ohm resistor throuh hole_1 | 4
20k | Resistor | R3 | resistor | 220ohm resistor throuh hole_1 | 1
220 ohm | Resistor | R6 | resistor | 220ohm resistor throuh hole_1 | 1
1K | Resistor | R7 | resistor | 220ohm resistor throuh hole_1 | 1
ESP32-DEVKIT-V1 | Dual core, Wi-Fi: 2.4 GHz up to 150 Mbits/s,BLE (Bluetooth Low Energy) and legacy Bluetooth, 32 bits, Up to 240 MHz | U1 | MODULE_ESP32_DEV KIT_V1 | ESP32-DEVKIT-V1 | 1
DM-OLED096-636 | 0.96â€ 128 X 64 MONOCHROME GRAPHIC OLED DISPLAY MODULE -I2C | U2 | MODULE_DM-OLED096-636 | DM-OLED096-636 | 1

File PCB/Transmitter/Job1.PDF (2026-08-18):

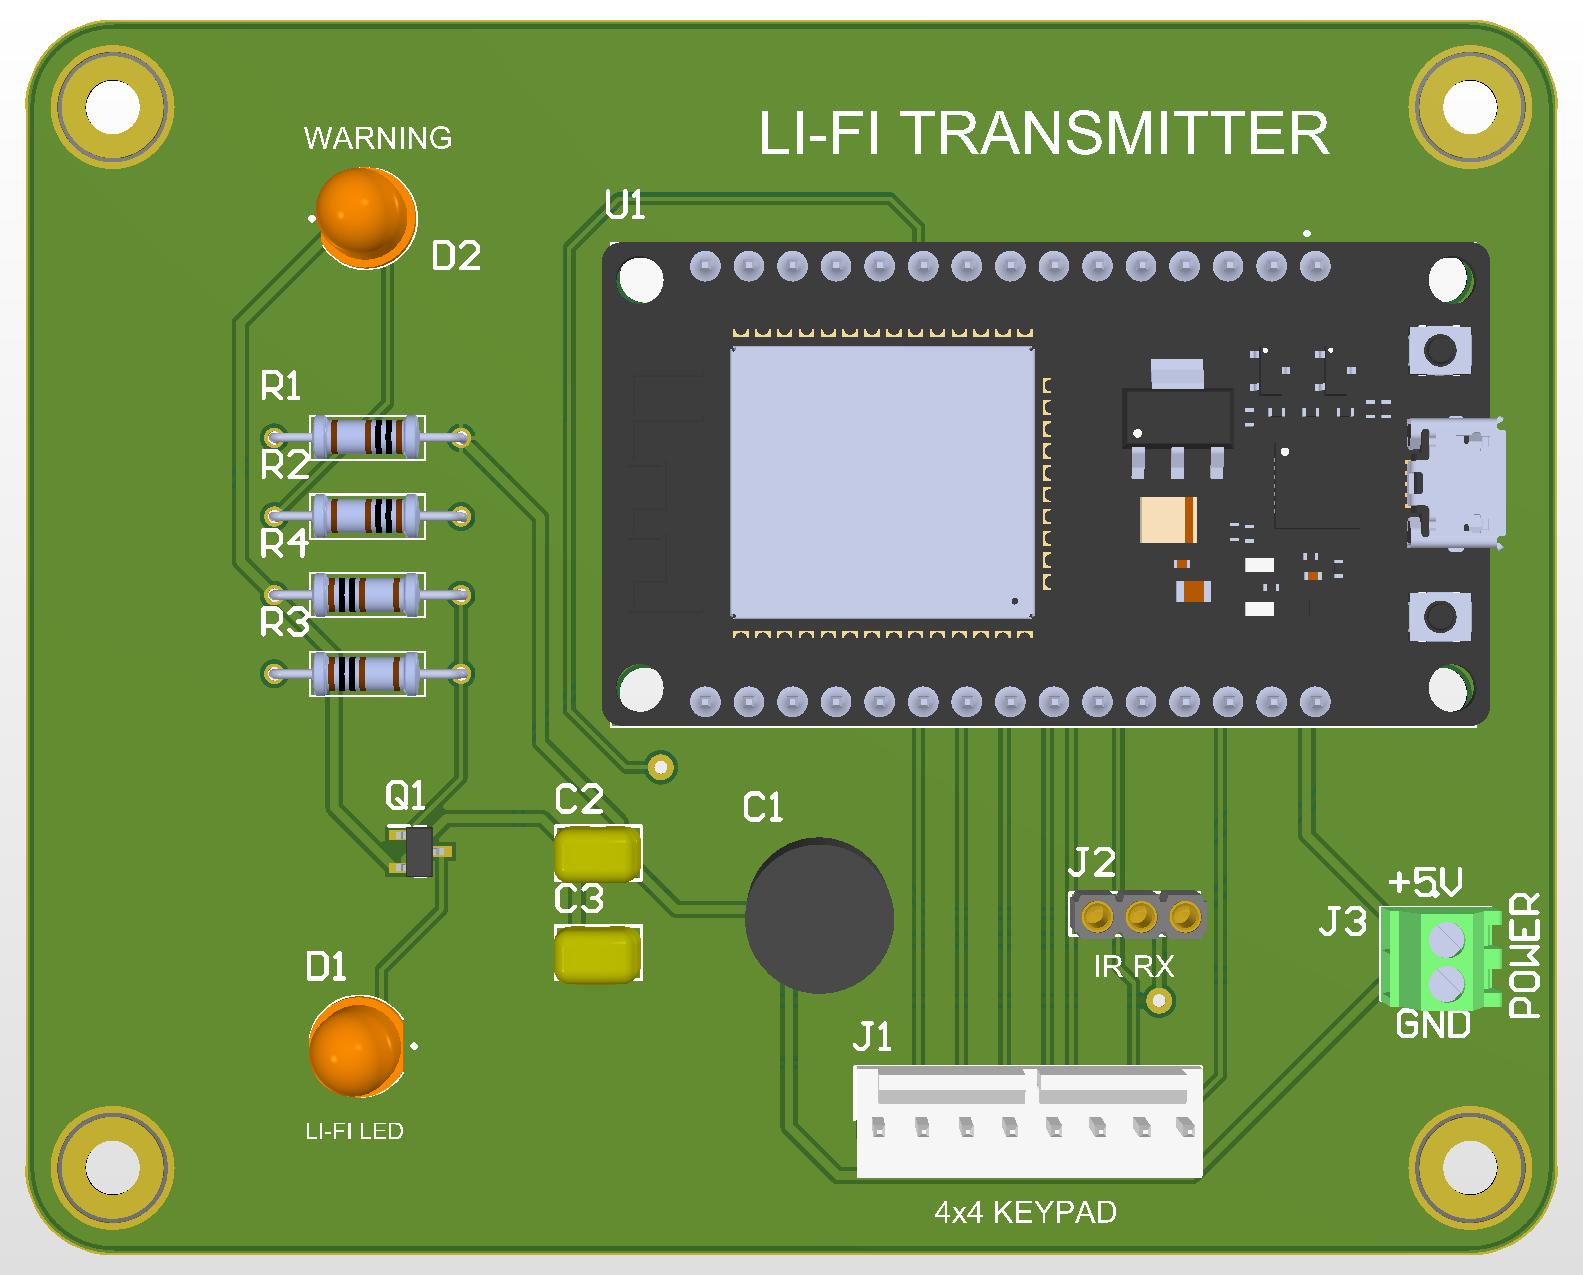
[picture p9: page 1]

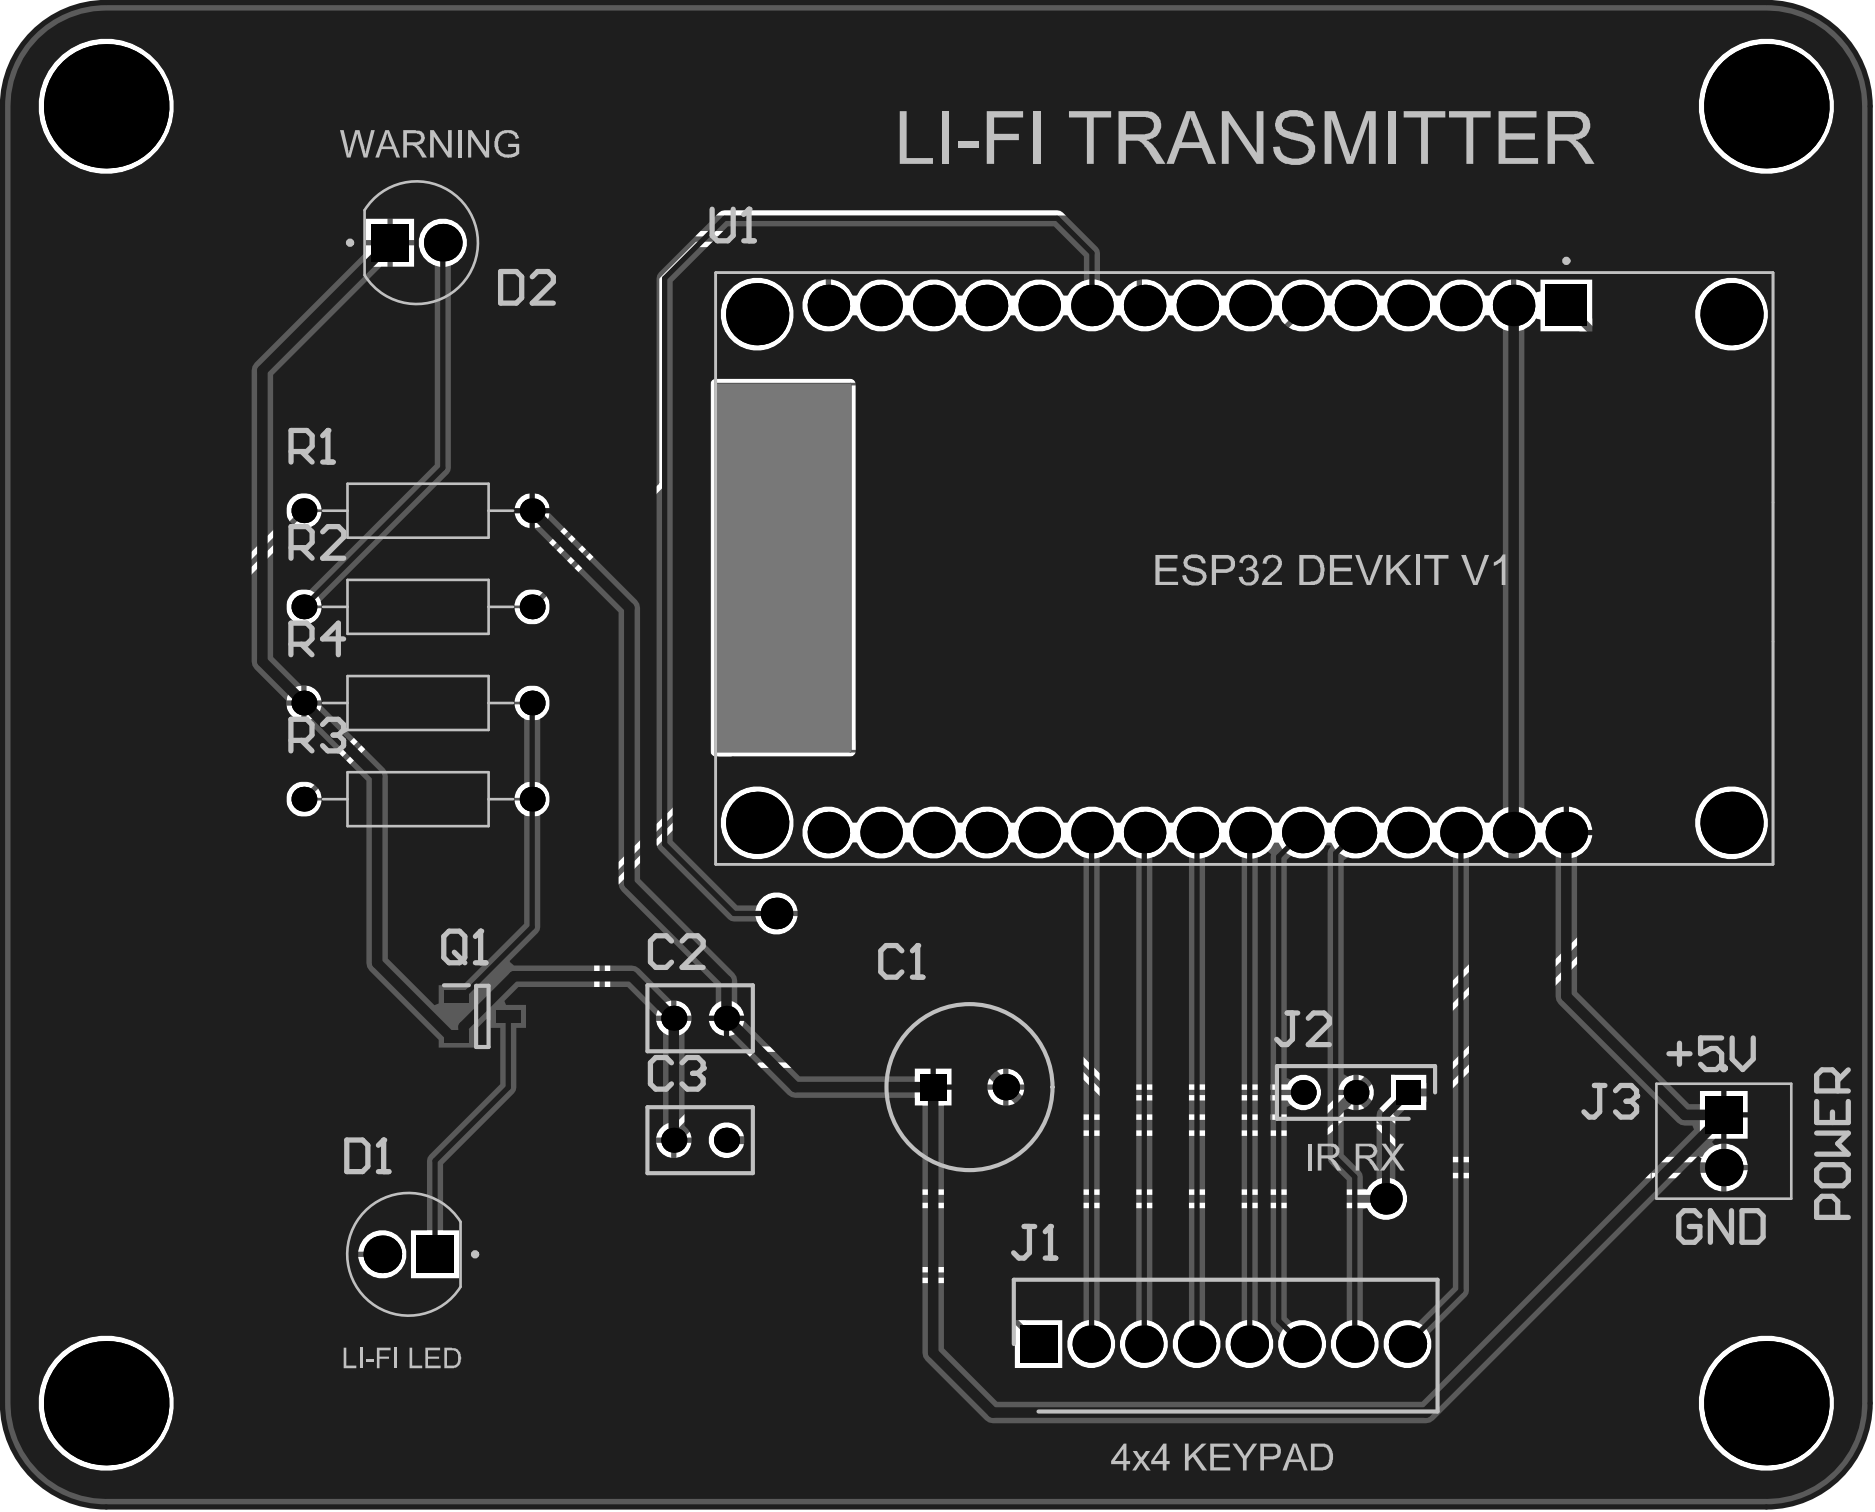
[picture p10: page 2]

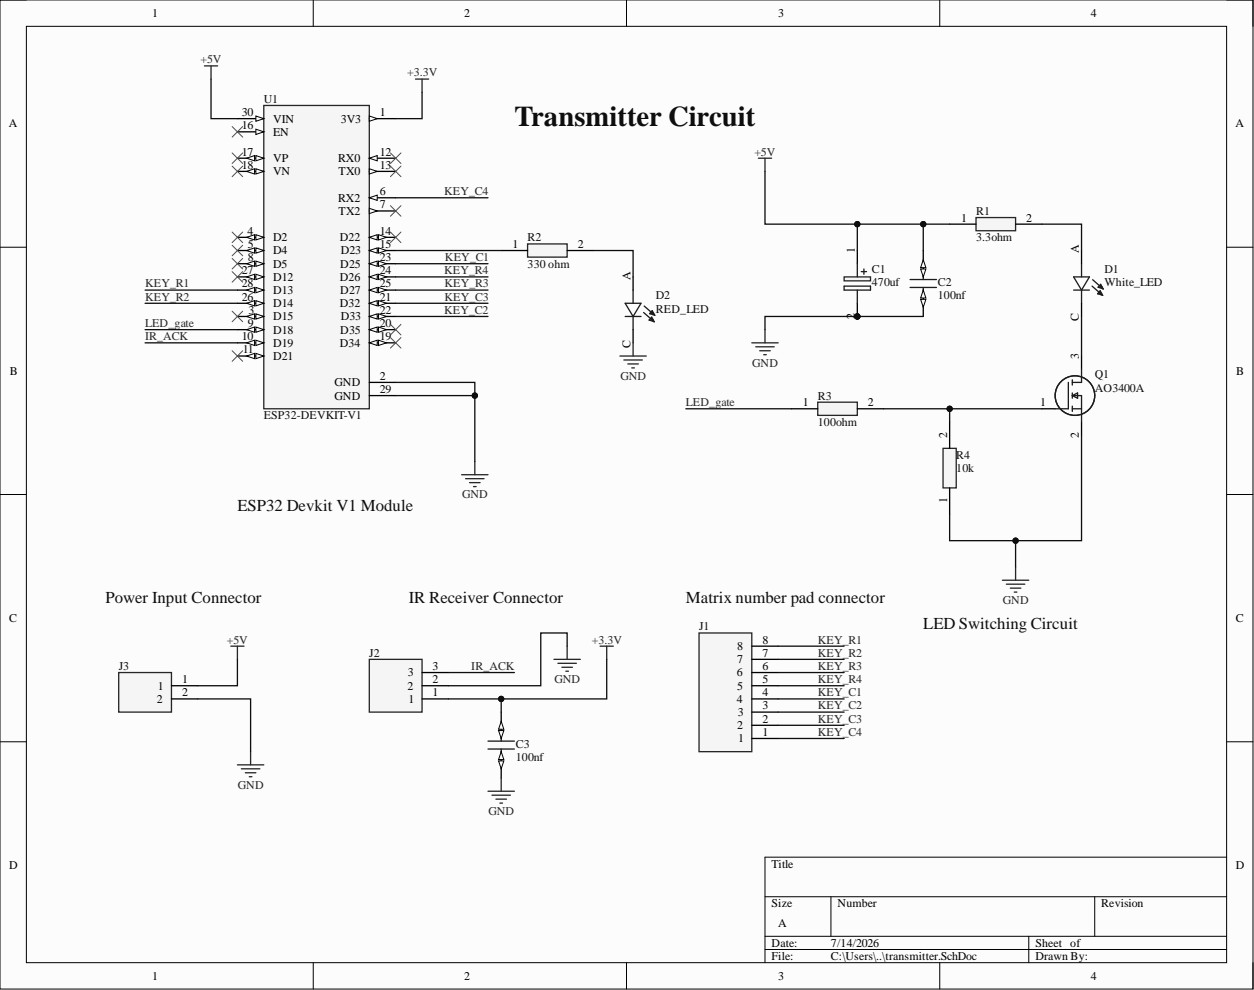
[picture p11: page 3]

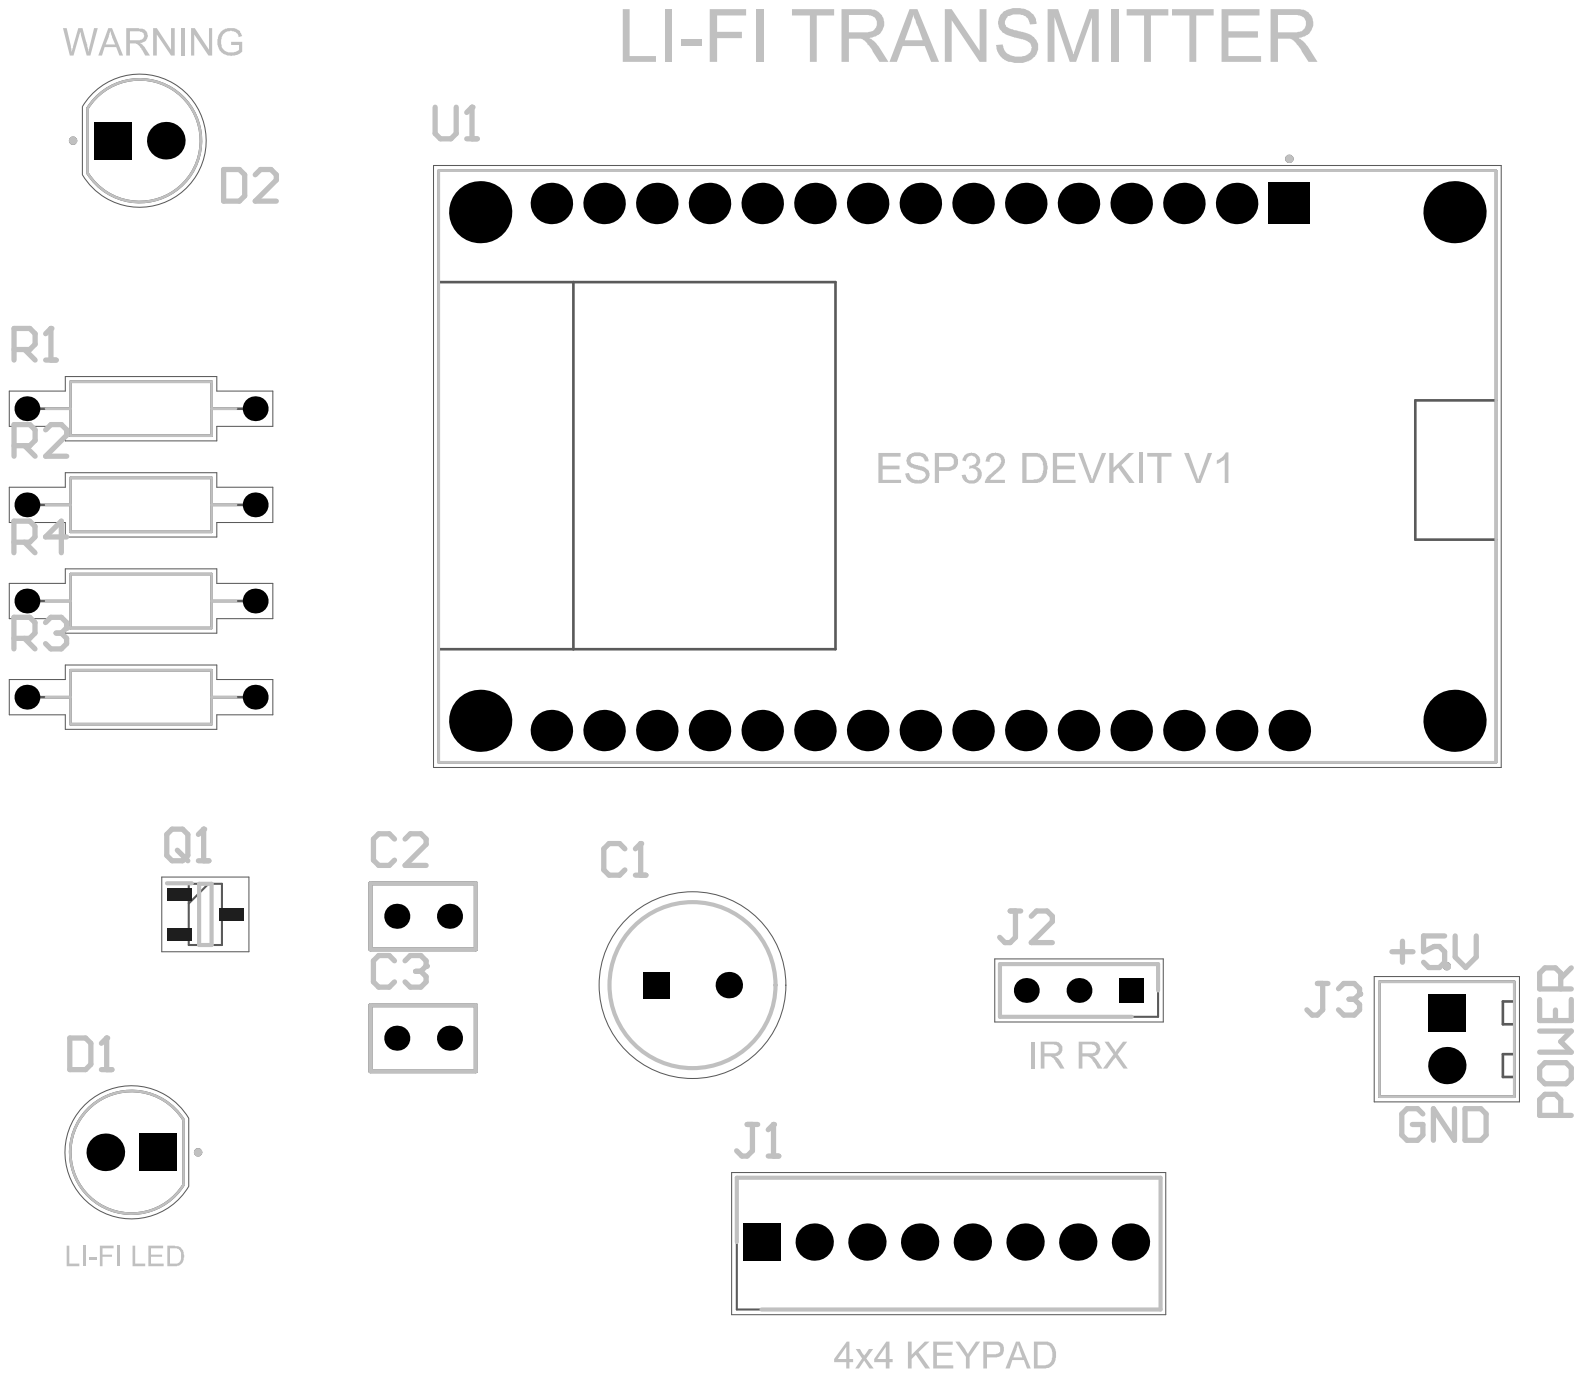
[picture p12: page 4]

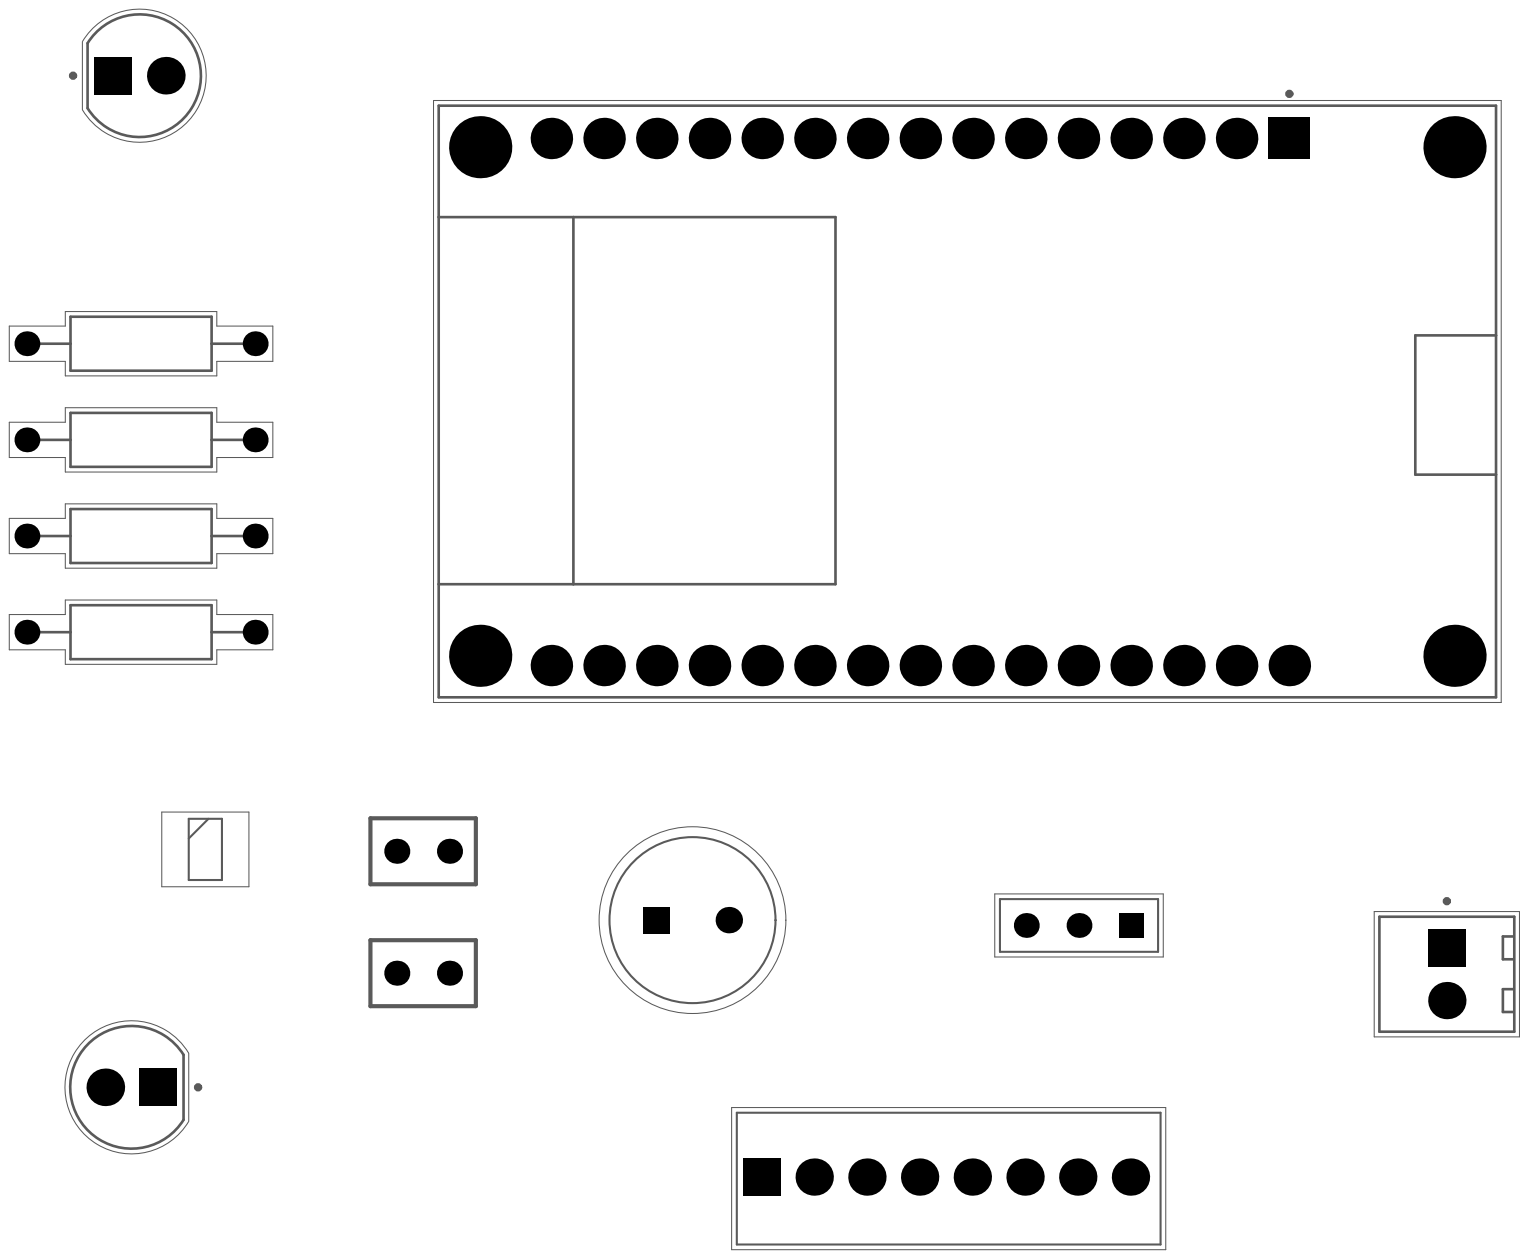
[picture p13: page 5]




Name | Description | Designator | Footprint | LibRef | Quantity
470uf | Capacitor Polarised | C1 | CAPPRD350W65D800 H1300 | 470uf | 1

White_LED | LED, 5MM, ORANGE; LED / Lamp Size: 5mm / T-1 3/4; LED Colour: Orange; Typ Luminous Intensity: 4.3mcd; Viewing Angle: ... | D1 | LEDRD254W57D500H 1070 | L08R5000Q1 | 1

RED_LED | LED, 5MM, ORANGE; LED / Lamp Size: 5mm / T-1 3/4; LED Colour: Orange; Typ Luminous Intensity: 4.3mcd; Viewing Angle: ... | D2 | LEDRD254W57D500H 1070 | L08R5000Q1 | 1

8 pin female header | Connector | J1 | SHDR8W99P0X254_1X 8_2017X635X1124P | 8 pin female header | 1

801-93-003-10-001000 | Connector | J2 | RHDR3W60P0X254_1 X3_762X254X701P | 801-93-003-10-001000 | 1

282834-2 | Terminal Block Connector PCB 2.54 mm 30-16 AWG Green 10 A 150 V M1.6 | TE Connectivity 282834-2 | J3 | TE_282834-2 | 282834-2 | 1

AO3400A | MOSFET (N-Channel) | Q1 | SOT95P280X125-3N | AO3400A | 1
3.3ohm | Resistor | R1 | resistor | 3.3ohm resistor throuh hole_1_1 | 1

330 ohm | Resistor | R2 | resistor | 3.3ohm resistor throuh hole_1_1 | 1

100ohm | Resistor | R3 | resistor | 100ohm resistor throuh hole_1_1 | 1

10k | Resistor | R4 | resistor | 10k resistor throuh hole_1 | 1

ESP32-DEVKIT-V1 | Dual core, Wi-Fi: 2.4 GHz up to 150 Mbits/s,BLE (Bluetooth Low Energy) and legacy Bluetooth, 32 bits, Up to 240 MHz | U1 | MODULE_ESP32_DEV KIT_V1 | ESP32-DEVKIT-V1 | 1

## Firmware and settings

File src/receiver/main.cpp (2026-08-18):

#include <Arduino.h>
#include <Adafruit_GFX.h>
#include <Adafruit_SSD1306.h>
#include <Wire.h>

#include "lifi_protocol.hpp"
#include "pin_config.hpp"

namespace {
constexpr uint8_t OLED_ADDRESS = 0x3C;
constexpr int8_t OLED_RESET_PIN = -1;
constexpr uint8_t IR_PWM_CHANNEL = 0;
constexpr uint8_t IR_PWM_RESOLUTION_BITS = 8;
constexpr uint8_t IR_PWM_DUTY = 128;

Adafruit_SSD1306 display(128, 64, &Wire, OLED_RESET_PIN);
bool display_available = false;
int32_t idle_level = 0;
uint32_t last_idle_report_ms = 0;
bool has_last_sequence = false;
uint8_t last_sequence = 0;

struct ReceivedPacket {
  uint8_t sequence;
  uint8_t length;
  char payload[lifi_protocol::MAX_MESSAGE_LENGTH + 1];
};

uint16_t readAdcAverage(uint8_t sample_count = 6) {
  uint32_t total = 0;
  for (uint8_t sample = 0; sample < sample_count; ++sample) {
    total += analogRead(receiver_pins::LIFI_ADC);
    delayMicroseconds(100);
  }
  return static_cast<uint16_t>(total / sample_count);
}

void waitUntilMicros(uint32_t target_time) {
  while (static_cast<int32_t>(micros() - target_time) < 0) {
    delayMicroseconds(50);
  }
}

bool isLightLevel(uint16_t sample, uint16_t bright_level, uint16_t dark_level) {
  return abs(static_cast<int32_t>(sample) - bright_level) <
         abs(static_cast<int32_t>(sample) - dark_level);
}

bool detectPreamble(uint32_t& frame_started_at, uint16_t& bright_level,
                    uint16_t& dark_level) {
  const uint16_t sample = readAdcAverage(3);
  const int32_t difference = abs(static_cast<int32_t>(sample) - idle_level);

  if (difference < lifi_protocol::MIN_OPTICAL_CONTRAST) {
    idle_level = ((idle_level * 31) + sample) / 32;
    delay(1);
    return false;
  }

  const uint32_t candidate_start = micros();
  delay(lifi_protocol::SYNC_CONFIRM_MS);
  const uint16_t confirmation = readAdcAverage(4);
  if (abs(static_cast<int32_t>(confirmation) - idle_level) <
      lifi_protocol::MIN_OPTICAL_CONTRAST) {
    return false;
  }

  frame_started_at = candidate_start;

  waitUntilMicros(frame_started_at + (lifi_protocol::SYNC_ON_MS / 2U) * 1000U);
  bright_level = readAdcAverage(10);

  waitUntilMicros(frame_started_at +
                  (lifi_protocol::SYNC_ON_MS +
                   lifi_protocol::CALIBRATION_OFF_MS / 2U) *
                      1000U);
  dark_level = readAdcAverage(10);

  const uint16_t contrast = static_cast<uint16_t>(
      abs(static_cast<int32_t>(bright_level) - dark_level));
  Serial.printf("Preamble: bright=%u dark=%u contrast=%u\n", bright_level,
                dark_level, contrast);

  return contrast >= lifi_protocol::MIN_OPTICAL_CONTRAST;
}

bool readManchesterBit(uint32_t data_started_at, size_t bit_index,
                       uint16_t bright_level, uint16_t dark_level,
                       bool& value) {
  const uint32_t bit_started_at =
      data_started_at + bit_index * lifi_protocol::BIT_DURATION_US;

  waitUntilMicros(bit_started_at + lifi_protocol::HALF_BIT_US / 2U);
  const uint16_t first_half = readAdcAverage(5);

  waitUntilMicros(bit_started_at + lifi_protocol::HALF_BIT_US +
                  lifi_protocol::HALF_BIT_US / 2U);
  const uint16_t second_half = readAdcAverage(5);

  const bool first_is_light =
      isLightLevel(first_half, bright_level, dark_level);
  const bool second_is_light =
      isLightLevel(second_half, bright_level, dark_level);

  if (first_is_light == second_is_light) {
    return false;
  }

  value = first_is_light;
  return true;
}

bool readByte(uint32_t data_started_at, size_t& bit_index,
              uint16_t bright_level, uint16_t dark_level, uint8_t& value) {
  value = 0;
  for (uint8_t bit = 0; bit < 8; ++bit, ++bit_index) {
    bool decoded_bit = false;
    if (!readManchesterBit(data_started_at, bit_index, bright_level, dark_level,
                           decoded_bit)) {
      return false;
    }
    value = static_cast<uint8_t>((value << 1U) | (decoded_bit ? 1U : 0U));
  }
  return true;
}

bool receivePacket(ReceivedPacket& packet) {
  uint32_t frame_started_at = 0;
  uint16_t bright_level = 0;
  uint16_t dark_level = 0;
  if (!detectPreamble(frame_started_at, bright_level, dark_level)) {
    return false;
  }

  const uint32_t data_started_at =
      frame_started_at +
      (lifi_protocol::SYNC_ON_MS + lifi_protocol::CALIBRATION_OFF_MS) * 1000U;
  size_t bit_index = 0;
  uint8_t frame[lifi_protocol::MAX_FRAME_LENGTH] = {};

  if (!readByte(data_started_at, bit_index, bright_level, dark_level, frame[0]) ||
      frame[0] != lifi_protocol::MAGIC ||
      !readByte(data_started_at, bit_index, bright_level, dark_level, frame[1]) ||
      !readByte(data_started_at, bit_index, bright_level, dark_level, frame[2])) {
    Serial.println("Rejected frame: invalid Manchester header or magic byte");
    return false;
  }

  packet.sequence = frame[1];
  packet.length = frame[2];
  if (packet.length == 0 || packet.length > lifi_protocol::MAX_MESSAGE_LENGTH) {
    Serial.println("Rejected frame: invalid payload length");
    return false;
  }

  for (size_t index = 0; index < packet.length; ++index) {
    if (!readByte(data_started_at, bit_index, bright_level, dark_level,
                  frame[lifi_protocol::HEADER_LENGTH + index])) {
      Serial.println("Rejected frame: invalid Manchester payload");
      return false;
    }
    packet.payload[index] =
        static_cast<char>(frame[lifi_protocol::HEADER_LENGTH + index]);
  }
  packet.payload[packet.length] = '\0';

  const size_t bytes_before_crc = lifi_protocol::HEADER_LENGTH + packet.length;
  uint8_t received_crc = 0;
  if (!readByte(data_started_at, bit_index, bright_level, dark_level,
                received_crc)) {
    Serial.println("Rejected frame: invalid Manchester CRC");
    return false;
  }

  const uint8_t calculated_crc = lifi_protocol::crc8(frame, bytes_before_crc);
  if (received_crc != calculated_crc) {
    Serial.printf("Rejected frame: CRC received=%02X calculated=%02X\n",
                  received_crc, calculated_crc);
    return false;
  }

  return true;
}

void showPacket(const ReceivedPacket& packet) {
  if (!display_available) {
    return;
  }

  display.clearDisplay();
  display.setCursor(0, 0);
  display.println("Li-Fi received");
  display.printf("Sequence: %u\n", packet.sequence);
  display.println();
  display.println(packet.payload);
  display.display();
}

void sendAcknowledgement() {
  delay(lifi_protocol::ACK_DELAY_MS);
  for (uint8_t burst = 0; burst < lifi_protocol::IR_BURST_COUNT; ++burst) {
    ledcWrite(IR_PWM_CHANNEL, IR_PWM_DUTY);
    delayMicroseconds(lifi_protocol::IR_BURST_US);
    ledcWrite(IR_PWM_CHANNEL, 0);
    delayMicroseconds(lifi_protocol::IR_GAP_US);
  }
}
}  // namespace

void setup() {
  Serial.begin(lifi_protocol::SERIAL_BAUD);

  pinMode(receiver_pins::IR_TX, OUTPUT);
  digitalWrite(receiver_pins::IR_TX, LOW);
  ledcSetup(IR_PWM_CHANNEL, lifi_protocol::IR_CARRIER_HZ,
            IR_PWM_RESOLUTION_BITS);
  ledcAttachPin(receiver_pins::IR_TX, IR_PWM_CHANNEL);
  ledcWrite(IR_PWM_CHANNEL, 0);

  pinMode(receiver_pins::LIFI_ADC, INPUT);
  analogReadResolution(12);
  analogSetPinAttenuation(receiver_pins::LIFI_ADC, ADC_11db);

  Wire.begin(receiver_pins::OLED_SDA, receiver_pins::OLED_SCL);
  display_available = display.begin(SSD1306_SWITCHCAPVCC, OLED_ADDRESS);
  if (display_available) {
    display.clearDisplay();
    display.setTextColor(SSD1306_WHITE);
    display.setTextSize(1);
    display.setCursor(0, 0);
    display.println("Li-Fi receiver");
    display.println("Waiting for light...");
    display.display();
  }

  delay(500);
  idle_level = readAdcAverage(32);
  Serial.println("Li-Fi receiver ready");
  Serial.printf("OLED: %s | initial ADC idle level: %ld\n",
                display_available ? "ready" : "not detected", idle_level);
}

void loop() {
  ReceivedPacket packet = {};
  if (receivePacket(packet)) {
    const bool duplicate = has_last_sequence && packet.sequence == last_sequence;
    if (duplicate) {
      Serial.printf("Duplicate sequence %u received; ACK repeated\n",
                    packet.sequence);
    } else {
      Serial.printf("Received sequence %u: \"%s\"\n", packet.sequence,
                    packet.payload);
      showPacket(packet);
      last_sequence = packet.sequence;
      has_last_sequence = true;
    }
    sendAcknowledgement();

    // Relearn the idle level after the optical frame and IR switching finish.
    delay(lifi_protocol::FRAME_GUARD_MS);
    idle_level = readAdcAverage(16);
  }

  if (millis() - last_idle_report_ms >= 2000) {
    last_idle_report_ms = millis();
    Serial.printf("Waiting | ADC idle=%ld current=%u\n", idle_level,
                  readAdcAverage(4));
  }
}

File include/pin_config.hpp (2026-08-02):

#pragma once

#include <stdint.h>

namespace transmitter_pins {
constexpr uint8_t LED_GATE = 18;
constexpr uint8_t WARNING_LED = 23;
constexpr uint8_t IR_ACK = 19;

constexpr uint8_t KEYPAD_ROWS[4] = {13, 14, 27, 26};
constexpr uint8_t KEYPAD_COLUMNS[4] = {25, 33, 32, 16};
}  // namespace transmitter_pins

namespace receiver_pins {
constexpr uint8_t LIFI_ADC = 34;
constexpr uint8_t IR_TX = 18;
constexpr uint8_t OLED_SDA = 21;
constexpr uint8_t OLED_SCL = 22;
}  // namespace receiver_pins

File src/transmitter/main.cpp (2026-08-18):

#include <Arduino.h>
#include <Keypad.h>

#include "lifi_protocol.hpp"
#include "pin_config.hpp"

namespace {
constexpr byte KEYPAD_ROW_COUNT = 4;
constexpr byte KEYPAD_COLUMN_COUNT = 4;

char keypad_map[KEYPAD_ROW_COUNT][KEYPAD_COLUMN_COUNT] = {
    {'1', '2', '3', 'A'},
    {'4', '5', '6', 'B'},
    {'7', '8', '9', 'C'},
    {'*', '0', '#', 'D'},
};

byte keypad_row_pins[KEYPAD_ROW_COUNT] = {
    transmitter_pins::KEYPAD_ROWS[0], transmitter_pins::KEYPAD_ROWS[1],
    transmitter_pins::KEYPAD_ROWS[2], transmitter_pins::KEYPAD_ROWS[3]};
byte keypad_column_pins[KEYPAD_COLUMN_COUNT] = {
    transmitter_pins::KEYPAD_COLUMNS[0], transmitter_pins::KEYPAD_COLUMNS[1],
    transmitter_pins::KEYPAD_COLUMNS[2], transmitter_pins::KEYPAD_COLUMNS[3]};

Keypad keypad(makeKeymap(keypad_map), keypad_row_pins, keypad_column_pins,
              KEYPAD_ROW_COUNT, KEYPAD_COLUMN_COUNT);

char message[lifi_protocol::MAX_MESSAGE_LENGTH + 1] = {};
size_t message_length = 0;
uint8_t sequence_number = 0;

void setOpticalLed(bool enabled) {
  digitalWrite(transmitter_pins::LED_GATE, enabled ? HIGH : LOW);
}

void sendManchesterBit(bool value) {
  setOpticalLed(value);
  delayMicroseconds(lifi_protocol::HALF_BIT_US);
  setOpticalLed(!value);
  delayMicroseconds(lifi_protocol::HALF_BIT_US);
}

void sendByte(uint8_t value) {
  for (int8_t bit = 7; bit >= 0; --bit) {
    sendManchesterBit((value & (1U << bit)) != 0U);
  }
}

void sendOpticalFrame(const char* payload, size_t payload_length,
                      uint8_t sequence) {
  uint8_t frame[lifi_protocol::MAX_FRAME_LENGTH] = {};
  frame[0] = lifi_protocol::MAGIC;
  frame[1] = sequence;
  frame[2] = static_cast<uint8_t>(payload_length);

  for (size_t index = 0; index < payload_length; ++index) {
    frame[lifi_protocol::HEADER_LENGTH + index] =
        static_cast<uint8_t>(payload[index]);
  }

  const size_t bytes_before_crc = lifi_protocol::HEADER_LENGTH + payload_length;
  frame[bytes_before_crc] = lifi_protocol::crc8(frame, bytes_before_crc);

  setOpticalLed(false);
  delay(lifi_protocol::IDLE_BEFORE_FRAME_MS);
  setOpticalLed(true);
  delay(lifi_protocol::SYNC_ON_MS);
  setOpticalLed(false);
  delay(lifi_protocol::CALIBRATION_OFF_MS);

  for (size_t index = 0; index <= bytes_before_crc; ++index) {
    sendByte(frame[index]);
  }

  setOpticalLed(false);
  delay(lifi_protocol::FRAME_GUARD_MS);
}

bool waitForAcknowledgement() {
  const uint32_t started_at = millis();
  uint32_t low_started_at = 0;

  while (millis() - started_at < lifi_protocol::ACK_TIMEOUT_MS) {
    if (digitalRead(transmitter_pins::IR_ACK) == LOW) {
      if (low_started_at == 0) {
        low_started_at = micros();
      } else if (micros() - low_started_at >= 150) {
        return true;
      }
    } else {
      low_started_at = 0;
    }
    delayMicroseconds(50);
  }
  return false;
}

void printMessageBuffer() {
  Serial.print("Message: \"");
  Serial.print(message);
  Serial.println("\"");
}

void transmitMessage() {
  if (message_length == 0) {
    Serial.println("Nothing to send. Enter a message first.");
    return;
  }

  Serial.printf("Sending sequence %u: \"%s\"\n", sequence_number, message);
  sendOpticalFrame(message, message_length, sequence_number);

  const bool acknowledged = waitForAcknowledgement();
  digitalWrite(transmitter_pins::WARNING_LED, acknowledged ? LOW : HIGH);
  Serial.println(acknowledged ? "ACK received" : "ACK timeout (link failure)");

  if (acknowledged) {
    ++sequence_number;
    message_length = 0;
    message[0] = '\0';
  }
}

void handleInputCharacter(char input) {
  if (input == '#') {
    transmitMessage();
    return;
  }

  if (input == '*') {
    if (message_length > 0) {
      message[--message_length] = '\0';
    }
    printMessageBuffer();
    return;
  }

  if (input < 32 || input > 126) {
    return;
  }

  if (message_length >= lifi_protocol::MAX_MESSAGE_LENGTH) {
    Serial.println("Message is full; press # to send or * to erase.");
    return;
  }

  message[message_length++] = input;
  message[message_length] = '\0';
  printMessageBuffer();
}
}  // namespace

void setup() {
  Serial.begin(lifi_protocol::SERIAL_BAUD);

  pinMode(transmitter_pins::LED_GATE, OUTPUT);
  pinMode(transmitter_pins::WARNING_LED, OUTPUT);
  pinMode(transmitter_pins::IR_ACK, INPUT_PULLUP);

  // Keep both LEDs off until an explicit hardware test is performed.
  digitalWrite(transmitter_pins::LED_GATE, LOW);
  digitalWrite(transmitter_pins::WARNING_LED, LOW);

  delay(500);
  Serial.println("Li-Fi transmitter ready");
  Serial.println("Keypad/Serial: type text, * erases, # sends (maximum 16 chars)");
  printMessageBuffer();
}

void loop() {
  const char keypad_key = keypad.getKey();
  if (keypad_key != NO_KEY) {
    Serial.printf("Keypad: %c\n", keypad_key);
    handleInputCharacter(keypad_key);
  }

  while (Serial.available() > 0) {
    const char serial_character = static_cast<char>(Serial.read());
    if (serial_character == '\r') {
      continue;
    }
    handleInputCharacter(serial_character == '\n' ? '#' : serial_character);
  }

  delay(2);
}
